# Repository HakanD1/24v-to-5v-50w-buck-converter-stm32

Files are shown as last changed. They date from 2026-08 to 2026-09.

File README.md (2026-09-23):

# STM32 Digitally Controlled 24V to 5V (50W) Buck Converter







A high-performance, fully custom **closed-loop digitally controlled buck converter** capable of stepping down a 24V DC input to a highly stable 5V DC output, providing up to 10A (50W) of continuous power. 

This project integrates custom PCB hardware, STM32 embedded software, mathematical control algorithms, and a Nextion HMI (Human-Machine Interface) into a single, cohesive industrial-grade prototype.
> ⚠️ **Project Status:** Rather than turning this into a physical product, I built it as an R&D exercise to combine the full design, simulation, and firmware development process into a single project and put my theoretical background into practice. As a result, the PCB, schematic, and firmware files in this repo have not been manufactured — they've only been verified through design and simulation.

## 🌟 Key Features

*   **Robust Power Delivery:** 24V to 5V step-down conversion with up to 10A current capacity.
*   **Digital PI Control:** Real-time Proportional-Integral (PI) control loop running on an STM32 microcontroller to dynamically adjust the 120 kHz PWM duty cycle for perfect voltage/current regulation.
*   **Precision Measurement:** Hall-effect current sensing (ACS712) and voltage divider networks, both buffered by MCP6001 Op-Amps for noise-immune ADC readings via DMA.
*   **Advanced Gate Driving:** FAN73711 high-speed gate driver implemented to efficiently switch the N-Channel power MOSFET with minimal switching losses.
*   **Multi-Stage Auxiliary Power:** Dual XL4015 buck stages (24V→12V, 12V→5V) and an AMS1117-3.3V LDO to safely isolate and power the logic and driver circuits.
*   **Comprehensive Protection:** Input fuse, varistor for overvoltage spikes, inrush current-limiting thermistor, and a software-controlled mechanical relay for emergency cutoff.
*   **Interactive UI:** Nextion display integration via USART for real-time monitoring (V, I, P) and on-the-fly PI tuning, calibration, and mode switching.

## 🛠️ Hardware Architecture

The custom dual-layer PCB is designed with best practices in mind, separating noisy power switching nodes from sensitive analog measuring circuits.

*   **Power Stage:** Features a 33µH power inductor and low-ESR capacitors optimized through MATLAB/Simulink and LTspice simulations to minimize output ripple.
*   **Protection Layer:** Hardware-level protection blocks ensuring safe start-up and transient spike absorption.
*   **Connectivity:** Features industry-standard ports including USB Type-C (for communication/future updates), 4-pin SWD (for flashing/debugging), and a 4-pin USART header for the HMI.

## 💻 Software & Control Strategy

Developed using **STM32CubeIDE** and the HAL library, the software architecture operates in a non-blocking, interrupt-driven manner:

1.  **ADC via DMA:** Voltage and current analog signals are continuously sampled in the background.
2.  **Calibration Layer:** Raw ADC data is scaled using dynamically adjustable calibration multipliers (`V_Cal`, `I_Cal`) and offsets to compensate for real-world component tolerances.
3.  **PI Algorithm:** Compares the measured value against the user-defined reference. The accumulated error (Integral) and current error (Proportional) dynamically update the timer's compare register to adjust the 120 kHz PWM duty cycle.
4.  **UART Parser:** A custom interrupt-driven parser processes commands from the Nextion screen (e.g., `KPV:2.50`, `SETV:5.00`) to tune the system on the fly.

## 📂 Repository Structure

*   `/bom` - Bill of Materials (BOM) files.
*   `/cubemx` - STM32CubeIDE project workspace and C/C++ source code.
*   `/gerber` - PCB manufacturing and Gerber files.
*   `/Nextion` - Nextion HMI display interface and GUI files.
*   `/schematic_pcb_3d` & `/STEP file` - 3D models and CAD files of the PCB.
*   `buck converter V6.*` - KiCad schematic and PCB design files.
*   `Buck_converter_24Vto5V.asc` - LTspice simulation model.
*   `buck_converter_24Vto5V.slx` - MATLAB/Simulink model.
*   `REPORT.pdf` - Comprehensive project documentation and theoretical calculations (in Turkish).

## 🚀 Getting Started

1.  Clone this repository: `git clone https://github.com/HakanD1/24v-to-5v-50w-buck-converter-stm32`
2.  Open the `/cubemx` project folder in **STM32CubeIDE**.
3.  Compile and flash the firmware onto the STM32F103C8T6 via the SWD interface.
4.  Load the `.tft` file (located in the `/Nextion` folder) onto your Nextion display.
5.  Supply 24V to the main input terminal, and monitor the live parameters on the Nextion screen.

## 📄 License

This project is licensed under the MIT License - see the [LICENSE](LICENSE) file for details.

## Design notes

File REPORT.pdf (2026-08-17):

# PROJE RAPORU

# STM32 Kontrollü 24 V–5 Buck Converter Tasarım

## Hazırlayan Hakan Dönmez

### Elektrik-Elektronik Mühendisliği

### Temmuz 2026

## 1. DEVRENİN ÇALIŞMA PRENSİBİ

Bu projenin temel amacı, giriş terminalinden uygulanan 24V DC gerilimi çıkışta

stabil bir 5V DC'ye düşüren ve 10A akım, 50W güç kapasitesi sunan bir buck converter

tasarlamaktır. Sistem, çıkış gerilimini ve akımını sürekli izleyerek closed-loop çalışan bir

güç kaynağı mimarisine sahiptir.

Sistemdeki farklı birimlerin çalışabilmesi için girişten alınan 24V besleme gerilimi

kademeli olarak düşürülmektedir. Bu doğrultuda, devrede iki adet XL4015 entegresi

kullanılarak sırasıyla 24V'tan 12V'a ve 12V'tan 5V'a düşürücü hatlar oluşturulmuştur. Ana

kontrol birimi olan STM32 mikrodenetleyicisi ve diğer dijital/analog komponentlerin

ihtiyaç duyduğu 3.3V besleme gerilimi ise, bu hattan beslenen bir AMS1117-3.3 LDO

aracılığıyla sağlanmaktadır. Ana güç dönüştürücünün aktarımı doğrudan STM32

mikrodenetleyicisi tarafından yönetilmektedir. Mikrodenetleyici, çıkış regülasyonunu

sağlamak için 120 kHz frekansında bir PWM sinyali üretir. Ancak STM32'nin 3.3V lojik

seviyesindeki çıkış sinyali, güç MOSFET'ini yüksek frekanslarda sürmek için tek başına

yeterli değildir. Bu sebeple devrede FAN73711 gate driver entegresi kullanılmıştır. Bu

driver, STM32'den gelen sinyali uygun seviyeye yükselterek MOSFET'in hızlı bir şekilde iletime ve kesime girmesini sağlar, böylece anahtarlama kayıpları en aza indirilir. İstenen

5V/10A çıkışın stabil kalması ve değişen yük durumlarında regülasyonun bozulmaması için

sistem bir geri besleme (feedback) mekanizması ile çalışır. Çıkış gerilimi ve hattan çekilen

akım değerleri, STM32'nin ADC pinleri üzerinden anlık olarak okunur. Okunan bu gerçek

değerler ile hedeflenen değerler arasındaki fark, mikrodenetleyici yazılımında koşan bir PI (Oransal-İntegral) kontrol algoritması tarafından işlenir. PI kontrolör, bu hatayı minimize

etmek üzere 120 kHz'lik PWM sinyalinin duty cycle değeri sürekli ve dinamik olarak

günceller.

Akım ölçümü için devrede ACS712 sensörü ve okunan sinyali mikrodenetleyiciye

uygun şekilde ölçeklendiren MCP6001 işlemsel op-amp yer almaktadır. Anahtarlama

gürültülerinin analog ölçümleri bozmaması amacıyla, STM32'nin analog besleme hattına

(VDDA) bir ferrite bead (FB1) eklenmiş ve yüksek kararlılıkta ADC okumaları elde

edilmesi hedeflenmiştir. Sistemin güvenliği ve dış donanım kontrolü için devreye bir adet

röle entegre edilmiştir. STM32 röle bobinini doğrudan süremediği için, kontrol işlemi bir

BC817 transistörünü tetikleyen GPIO pini üzerinden gerçekleştirilir. Sistemdeki anlık

gerilim, akım verileri ve genel çalışma durumu, STM32'nin USART1 hatları üzerinden

Nextion ekrana iletilerek kullanıcı arayüzüne aktarılır. Ayrıca, güç hatlarının durumunu

görselleştirmek için şemada durum LED'leri bulunmakta olup, cihazla iletişim ve yazılım

güncelleme işlemleri için bir USB Type-C portu ile BOOT0 butonu sisteme dahil edilmiştir.

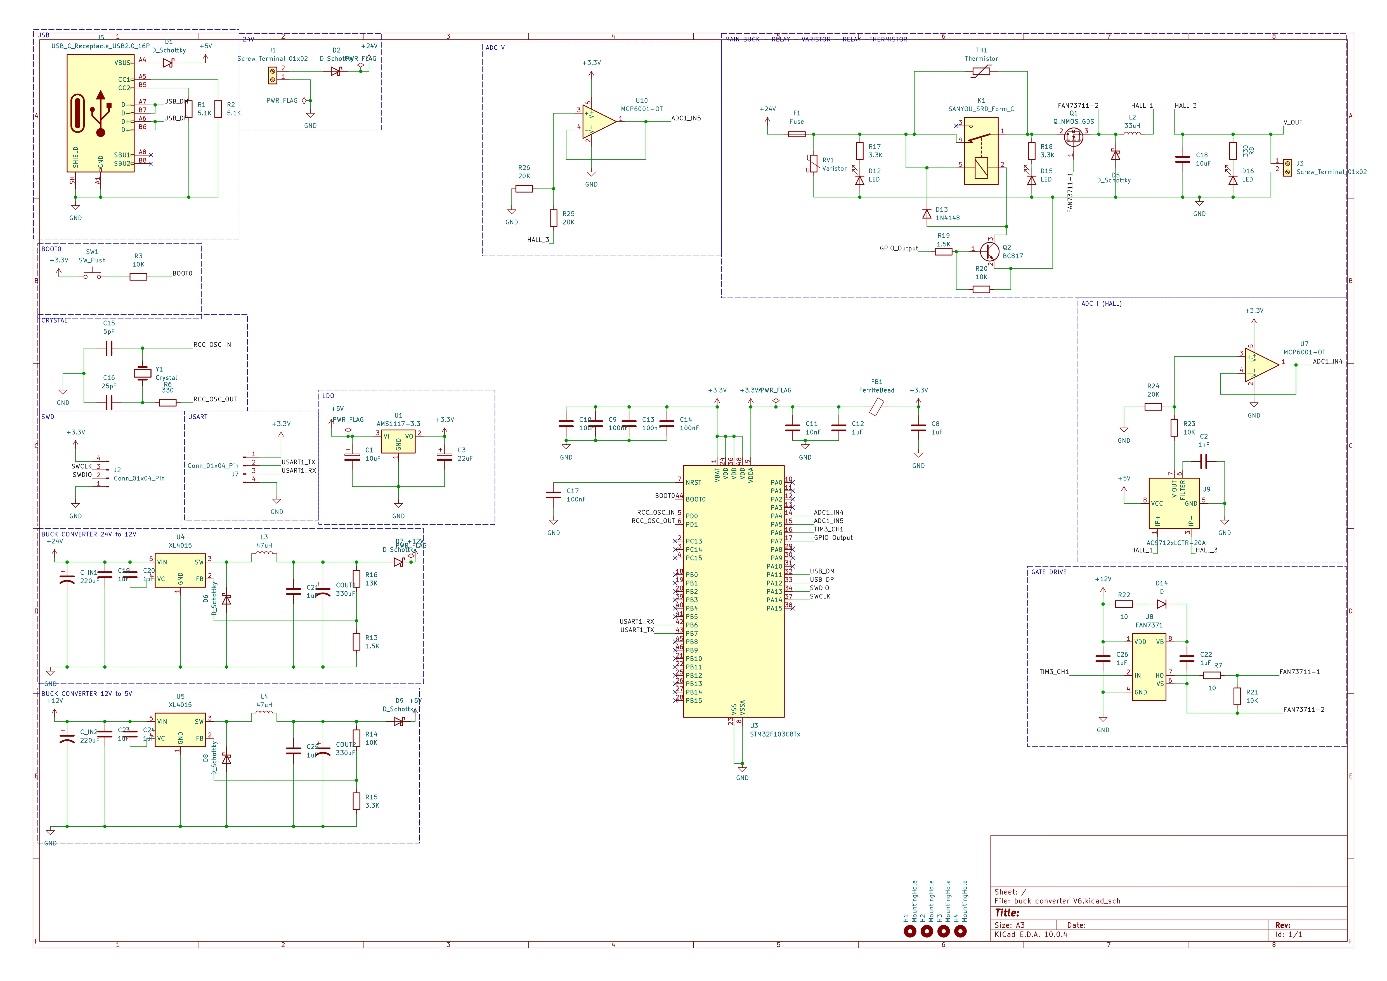
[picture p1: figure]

Şekil 1

## 2. SİSTEM MİMARİSİ VE YAPISI

### 1. BUCK CONVERTER 24V-12V, 12V-5V ve LDO Blokları

Sistemin ana güç aktarımından bağımsız olarak, STM32 ve Gate Driver birimlerinin

uyanıp çalışabilmesi için J1 terminalinden giren 24V ana besleme kademeli olarak

düşürülür. Bu amaçla, stok durumu, maliyet ve üretici datasheet yönergeleri göz önüne

alınarak iki adet XL4015 Buck seçilmiştir. Şemadaki U4 bloğu 24V girişini alıp Gate Driver

(FAN7371) için 12V üretirken; U5 bloğu bu 12V'u alarak sistemi besleyecek 5V gerilimini

elde eder. D2 diyodu ile ters akım koruma amacı ile yerleştirilmiştir.

Bu düşürücü bloklardaki pasif komponentler doğrudan datasheet referanslarıyla

belirlenmiştir. Temel enerji depolama ve büyük voltaj dalgalanmalarını sönümlemek için

girişte 220µF (CIN1, CIN2), çıkışta 330µF (COUT1, COUT2) alüminyum elektrolitik

kondansatörler kullanılmıştır. Anahtarlama sırasında oluşan yüksek frekanslı elektriksel

gürültüleri filtrelemek amacıyla da bu kondansatörlere paralel olarak daha hızlı tepki veren

düşük sığalı seramik kondansatörler (C19, C20 vb.) eklenmiştir. Akım dalgalanmasını

optimum seviyede tutmak için datasheet hesaplamalarına uygun 47µH bobinler (L3, L4) ve

anahtarlama esnasında akımın devreyi tamamlaması için D7/D9 Schottky diyotları devrede

yer alır. Çıkış gerilimlerini 12V ve 5V'a sabitlemek için ise geri besleme (FB) pinlerine

datasheet formüllerine göre belirlenmiş hassas direnç bölücüler (R13/R16 ve R14/R15)

bağlanmıştır.

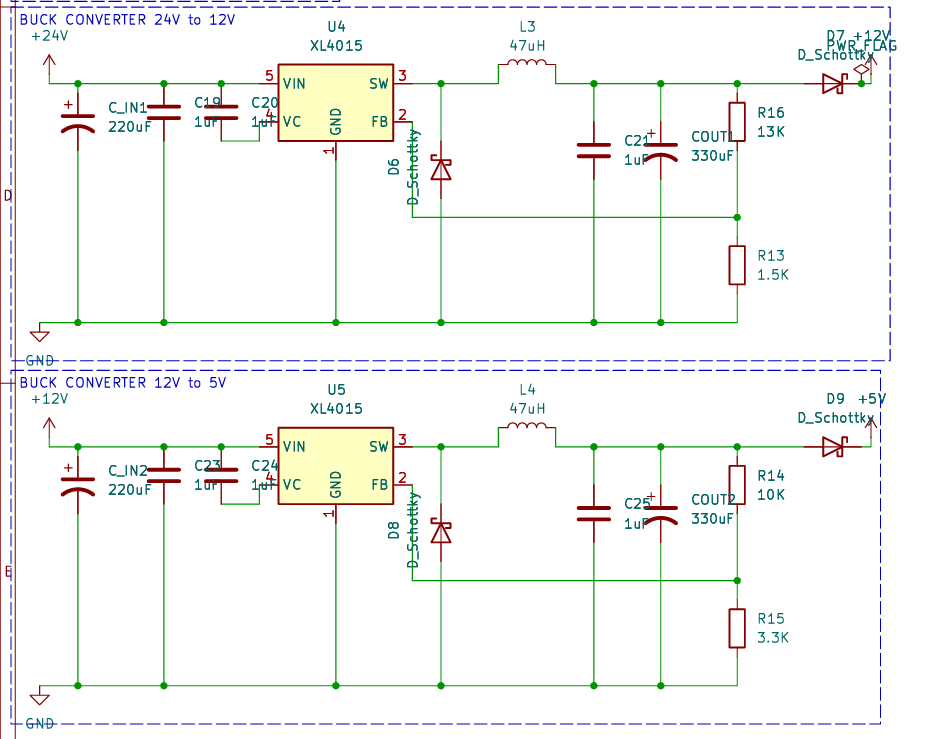
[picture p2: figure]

Şekil 2

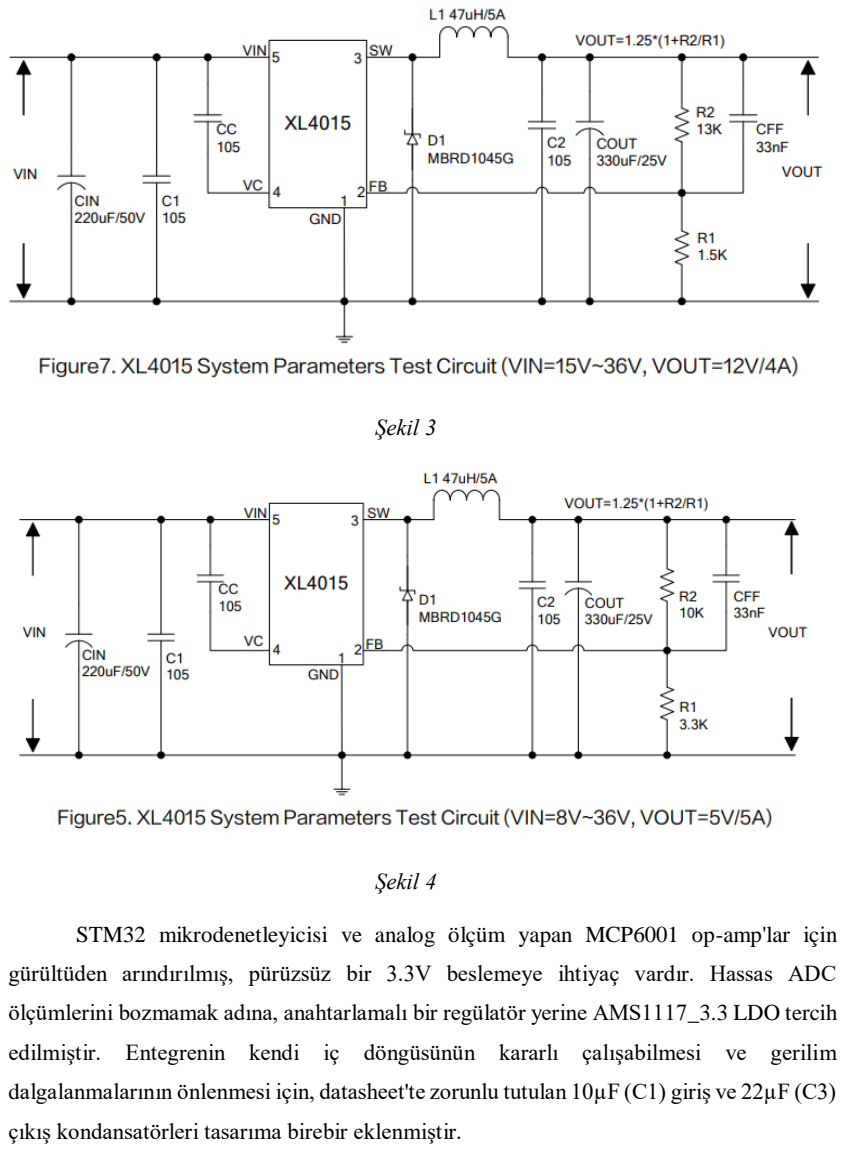
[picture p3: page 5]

Şekil 3

Şekil 4

STM32 mikrodenetleyicisi ve analog ölçüm yapan MCP6001 op-amp'lar için

gürültüden arındırılmış, pürüzsüz bir 3.3V beslemeye ihtiyaç vardır. Hassas ADC

ölçümlerini bozmamak adına, anahtarlamalı bir regülatör yerine AMS1117_3.3 LDO tercih

edilmiştir. Entegrenin kendi iç döngüsünün kararlı çalışabilmesi ve gerilim

dalgalanmalarının önlenmesi için, datasheet'te zorunlu tutulan 10µF (C1) giriş ve 22µF (C3)

çıkış kondansatörleri tasarıma birebir eklenmiştir.

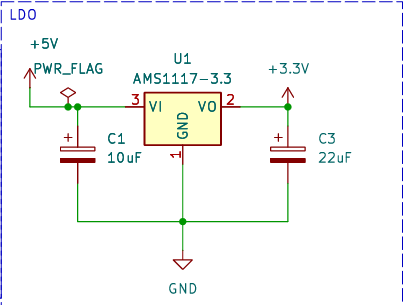
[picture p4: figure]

Şekil 5

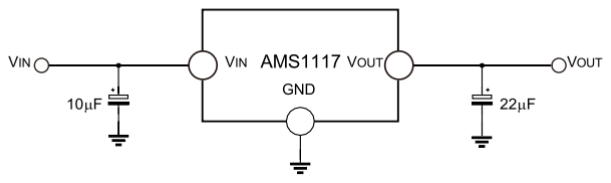
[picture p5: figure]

Şekil 6

### 2. STM32, CRYSTAL ve BOOT0 Blokları

Sistemin tüm kapalı çevrim kontrol algoritmalarını (PI kontrol), 120 kHz frekanslı

PWM üretimini ve kullanıcı arayüzü haberleşmesini yöneten ana beyin olarak

STM32F103C8T6 mikrodenetleyicisi kullanılmıştır. Mikrodenetleyicinin dijital besleme

(VDD) pinlerine, dijital işlemlerden kaynaklanan anlık gerilim düşümlerini ve gürültüleri

engellemek amacıyla 100nF değerinde decoupling kondansatörleri (C9, C10, C13, C14)

yerleştirilmiştir. Ayrıca, akım ve gerilim ölçümlerinin yapıldığı hassas analog besleme hattı

(VDDA), anahtarlama gürültülerinden etkilenmemesi için dijital hattan bir ferrite bead

(FB1) ile izole edilmiş ve ADC okumalarının kararlılığı güvence altına alınmıştır.

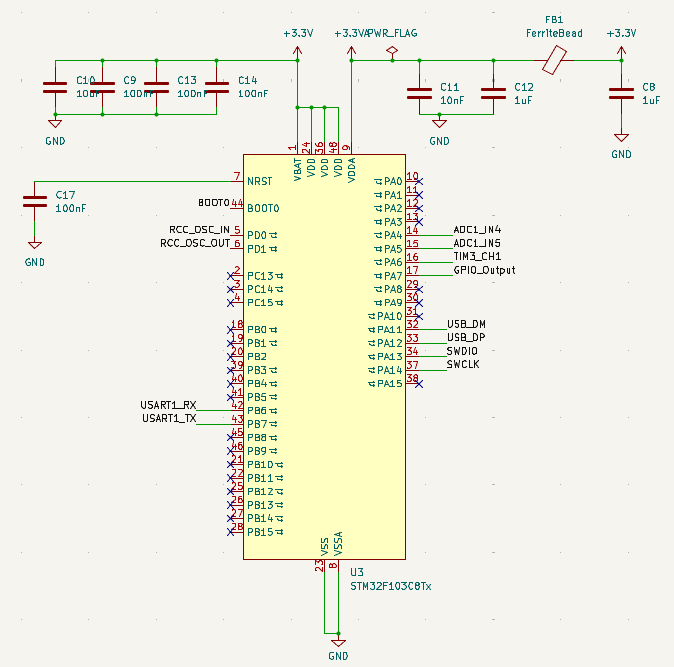
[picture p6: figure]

Şekil 7

Sistemde yüksek frekanslı PWM sinyallerinin hassas bir şekilde üretilebilmesi ve

UART gibi zamanlamaya duyarlı haberleşme protokollerinin sorunsuz çalışabilmesi için

mikrodenetleyicinin dahili osilatörü yerine harici bir kristal osilatör devresi tercih

edilmiştir. Kullanılan kristalin kararlı bir şekilde titreşime geçebilmesi ve dış etkenlere bağlı

frekans kaymalarının önlenmesi için, datasheet yönergelerine uygun olarak 25pF değerinde

yük kondansatörleri (C15, C16) ile desteklenmiştir.

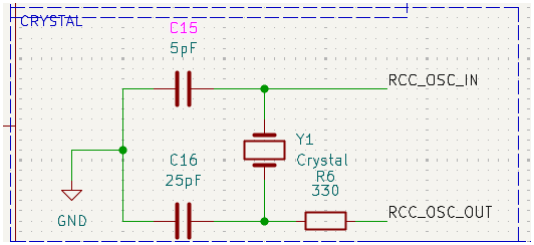
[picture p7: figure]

Şekil 8

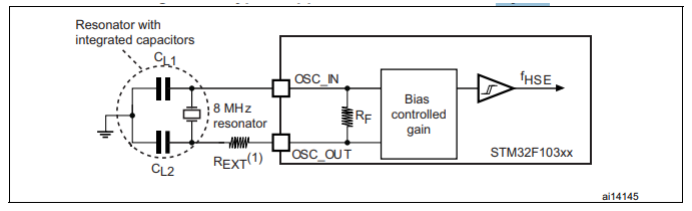
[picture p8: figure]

Şekil 9

Cihazın programlanması ve yazılım güncellemelerinin kolayca yapılabilmesi için

donanımsal bir BOOT0 kontrol bloğu tasarıma dahil edilmiştir. BOOT0 pini, normal

çalışma durumunda 10k değerinde bir direnç (R3) ile toprağa çekilerek (pull-down)

sistemin her açılışta ana hafızadan başlaması güvence altına alınmıştır. Yazılım atılacağı

zaman ise bir push buton (SW1) vasıtasıyla bu pine 3.3V verilerek mikrodenetleyicinin

donanımsal olarak bootloader moduna geçmesi sağlanır. Ek olarak, elektriksel gürültülerin

veya dalgalanmaların mikrodenetleyiciyi yanlışlıkla resetlemesini engellemek amacıyla

NRST pinine 100nF değerinde bir filtre kondansatörü (C17) eklenmiştir.

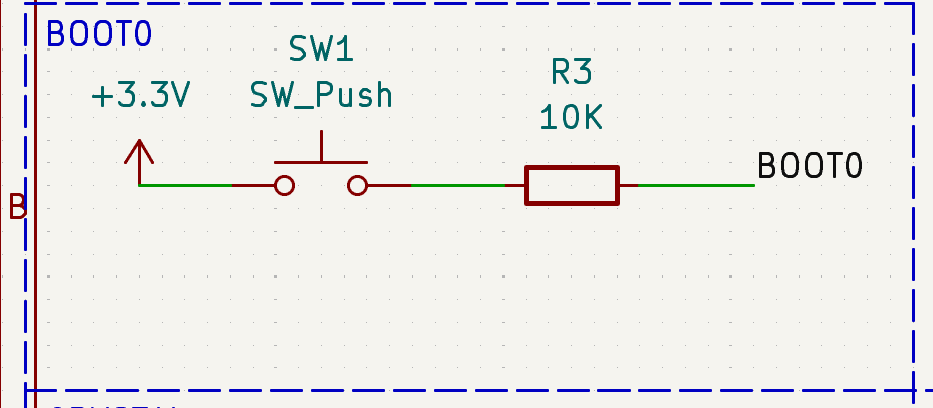
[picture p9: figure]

Şekil 10

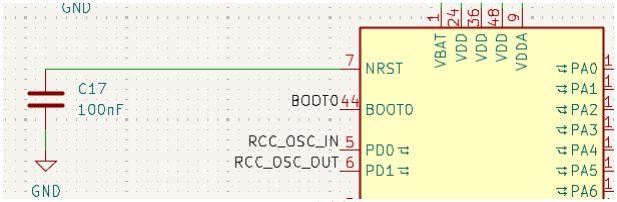
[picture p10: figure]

Şekil 11

### 3. MAIN BUCK ve GATE DRIVE Blokları

Devrenin temel amacı olan 24V girişten 5V ve 10A (50W) regüleli çıkış elde etme

işlemi bu katmanda gerçekleşir ve sistemin verimliliği açısından en kritik bölümdür.

STM32 tarafından üretilen 3.3V lojik seviyesindeki 120 kHz frekanslı PWM sinyali, güç

MOSFET'inin (Q1) gate kapasitansını bu kadar yüksek hızlarda kayıpsız sürmek için tek

başına yeterli değildir. Bu nedenle aracı bir driver olarak 12V ile beslenen FAN7371

entegresi kullanılmıştır. Sistemde N-Kanal bir MOSFET konumlandırıldığı için, driver

devresinde D14 diyotu ve C22 (1µF) kondansatörü ile bir bootstrap devresi oluşturularak

MOSFET'in tam iletime geçmesi için gereken yüksek geçit gerilimi sağlanmıştır.

MOSFET'in iletime geçme hızını kontrol etmek ve elektromanyetik gürültüleri önlemek

için geçit ucuna 10 ohm değerinde bir seri direnç (R7) eklenmiş; driver pasifken

MOSFET'in güvenli bir şekilde kesimde kalmasını garanti altına almak için ise 10k

değerinde bir pull-down direnci (R21) kullanılmıştır.

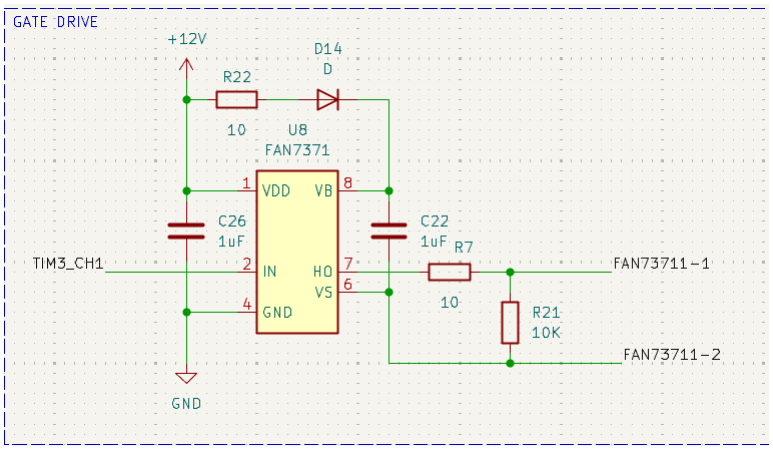
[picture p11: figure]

Şekil 12

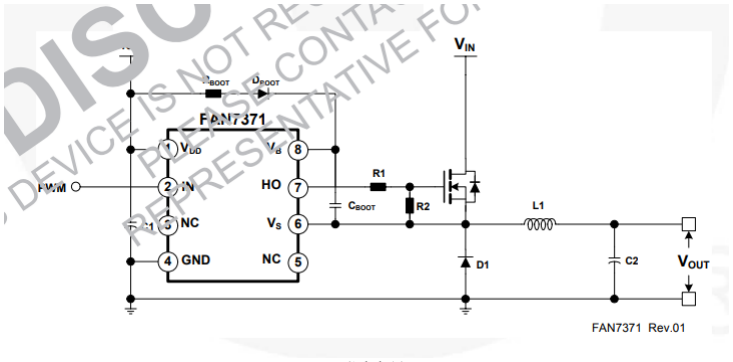
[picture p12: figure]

Şekil 13

Dönüştürücü topolojisinin anahtarlama elemanı olarak, ısıl kayıpları minimumda

tutmak adına düşük iletim direncine sahip bir N-Kanal MOSFET (Q1) görev yapmaktadır.

MOSFET kesime gittiğinde bobin üzerinde biriken manyetik enerjinin devreyi

tamamlaması işlemi, anahtarlama hızlarına ayak uydurabilen ve ileri yön gerilim düşümü

düşük olan bir Schottky diyot üzerinden sağlanmaktadır. Güç aktarımının ana pasif

elemanları olan 33µH değerindeki L2 bobini ve 10µF değerindeki C18 çıkış kondansatörü,

Bölüm 3’te detaylandırılan MATLAB/Simulink ve LTspice simülasyon testleri sonucunda elde edilen optimum kararlılık verilerine dayanılarak belirlenmiştir. 120 kHz gibi yüksek

bir anahtarlama frekansı kullanılması sayesinde hem bobinin fiziksel boyutu küçültülmüş

hem de 10A gibi yüksek bir akımda bile çıkış dalgalanması simülasyonlarda hedeflenen

ideal seviyelerde tutulmuştur.

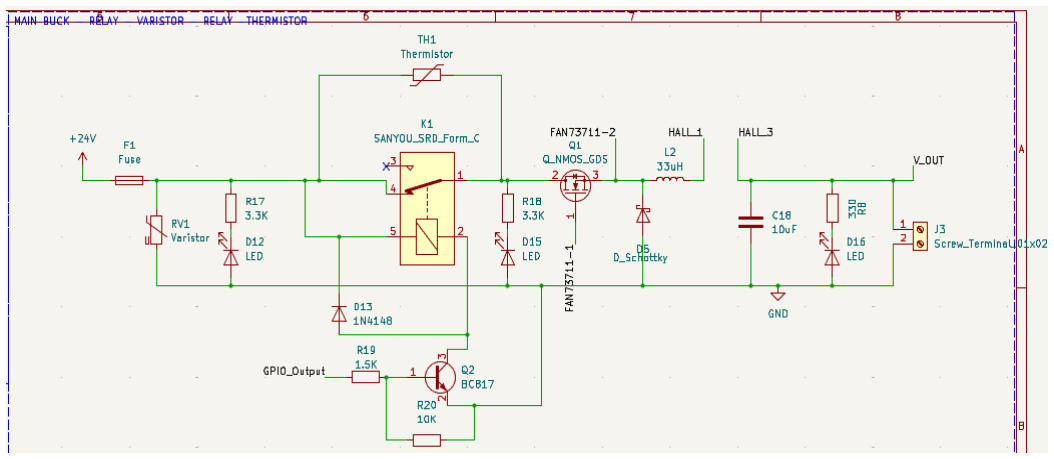
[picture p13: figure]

Şekil 14

Sistemdeki güç akışını ve donanımın çalışma durumunu görsel olarak anlık takip

edebilmek amacıyla devrenin kritik noktalarına durum LED'leri (D12, D15 ve D16)

yerleştirilmiştir. Bu LED'ler, röle sonrası güç hattının, anahtarlama katının ve regüle edilmiş

5V ana çıkışın (V_OUT) aktif olup olmadığını kullanıcıya donanımsal bir geri bildirim

olarak sunar. Bu kattaki güç bileşenlerinin tamamı, çıkışta hedeflenen sürekli 10A akım

yükünü ısıl ve elektriksel olarak güvenle taşıyabilecek toleranslara sahip parçalar arasından

seçilmiştir. Seçim sürecinde donanımların piyasadaki stok durumu, uygun maliyetli

olmaları ve güvenli çalışma sınırlarına tam uyumları en temel kriterler olmuştu

### 4. ADC_V ve ADC_I Blokları

Sistemin kapalı çevrim kontrol yapabilmesi ve aşırı akım koruması sağlayabilmesi

için çıkış geriliminin ve akımının anlık olarak ölçülmesi gerekmektedir. Çıkış geriliminin

(V_OUT) okunması işlemi ADC_V bloğunda gerçekleştirilir. STM32'nin analog giriş

pinleri maksimum 3.3V referans değerine kadar okuma yapabildiği için, 5V'luk ana çıkış

gerilimi doğrudan mikrodenetleyiciye verilmez; bunun yerine R25 (20k) ve R26 (20k)

dirençlerinden oluşan bir gerilim bölücü ağ ile yarı yarıya (1/2 oranında) düşürülür. ADC

pinine giden sinyalin empedansını düşürmek ve dış gürültülerden arındırılmış kararlı bir okuma sağlamak amacıyla, bu zayıflatılmış sinyal U10 referanslı MCP6001 işlemsel

yükselteci (op-amp) üzerinden geçirilir. Bir gerilim izleyici (voltage follower/buffer) olarak

kurulan bu op-amp'ın çıkışı, ölçüm yapılabilmesi için mikrodenetleyicinin ADC1_IN5

pinine iletilir.

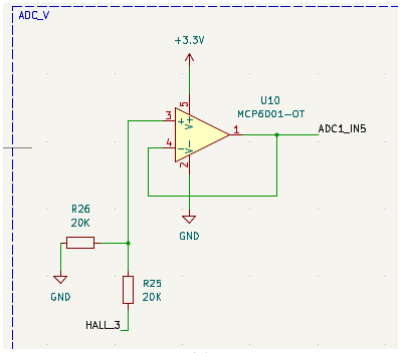
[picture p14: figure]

Şekil 15

Çıkış akımının ölçümü için ADC_I bloğunda Hall-effect (manyetik) prensibiyle

çalışan ACS712xLCTR-20A akım sensörü kullanılmıştır. Bu sensör, akım yoluna fiziksel

bir şönt direnç eklemediği için devrede güç kaybı (insertion loss) yaratmaz ve ölçüm katını

yüksek akım hattından elektriksel olarak tamamen izole eder. ACS712 sensörü 5V besleme

ile çalıştığı için, okuduğu akım değerine göre ürettiği analog çıkış voltajı

mikrodenetleyicinin 3.3V'luk güvenli okuma sınırını aşabilmektedir. Bu donanımsal sorunu

çözmek için sensör çıkışına R24 (20k) ve R23 (10k) dirençlerinden oluşan bir bölücü ağ

eklenerek sinyal genliği güvenli bir seviyeye ölçeklenmiştir. Sinyal üzerindeki elektriksel

gürültüleri filtrelemek ve sensörün bant genişliğini ayarlamak için sensörün FILTER pinine

1nF değerinde bir kondansatör (C2) bağlanmıştır. Voltaj okuma bloğunda olduğu gibi, akım

sensöründen gelen bu ölçeklenmiş sinyal de U7 referanslı bir diğer MCP6001 op-amp ile

tamponlanarak (buffer) mikrodenetleyicinin ADC1_IN4 pinine güvenli bir şekilde aktarılır.

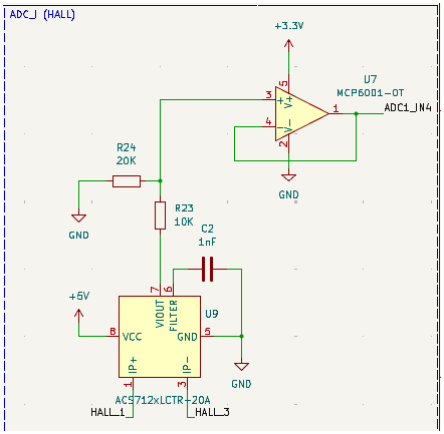
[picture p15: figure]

Şekil 26

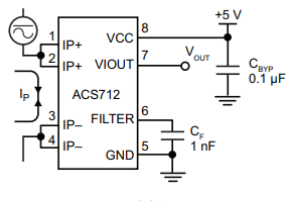
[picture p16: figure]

Şekil 17

### 5. PIN ÇIKIŞLARI ve ARAYÜZ (USART, SWD, USB)

Sistemin dış dünya ile haberleşmesi, programlanması ve harici donanım bağlantıları

için çeşitli arayüz portları şemaya entegre edilmiştir. Güncel bağlantı standartlarına uygun

olarak tasarıma 16 pinli bir USB Type-C portu (J1) eklenmiştir. Bu port üzerinden

mikrodenetleyicinin PA11 ve PA12 pinlerine USB veri hatları (USB_DM ve USB_DP)

yönlendirilmiştir. Cihazın bağlandığı güç kaynağına kendini standart bir enerji tüketicisi

(UFP) olarak tanıtabilmesi için, Type-C bağlantı spesifikasyonlarına tamamen uygun

şekilde CC1 ve CC2 konfigürasyon pinlerine 5.1k değerinde pull-down dirençleri (R1 ve

R2) eklenmiştir.

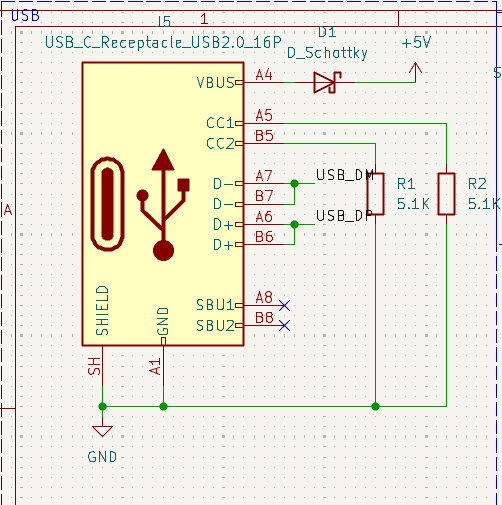
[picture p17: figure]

Şekil 18

Mikrodenetleyicinin programlanması ve donanımsal hata ayıklama işlemlerinin kart

üzerinde pratik şekilde gerçekleştirilebilmesi için 4 pinli standart bir SWD konnektörü (J2)

tasarlanmıştır. | Bu | konnektör | üzerinden | +3.3V | besleme, | GND | hatları | ve

mikrodenetleyicinin PA13 (SWDIO) ile PA14 (SWCLK) pinleri doğrudan dışarıya

aktarılmıştır. Sistemin harici donanımlarla ve özellikle kullanıcı arayüzü ile (HMI/Ekran)

seri haberleşebilmesi amacıyla donanıma 4 pinli bir USART konnektörü (J7) de dahil

edilmiştir. Bu port üzerinden cihazın toprağı (GND), +3.3V beslemesi ve

mikrodenetleyicinin PB6 (USART1_TX) ile PB7 (USART1_RX) pinleri dış bağlantıya

sunularak çift yönlü seri veri alışverişi fiziksel olarak mümkün kılınmıştır.

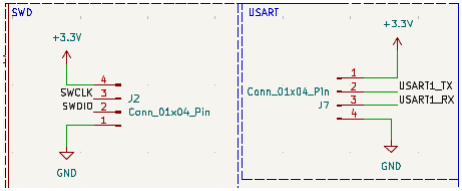
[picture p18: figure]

Şekil 19

### 6. KORUMA ve GÖSTERGE Blokları (Relay, Varistor, Thermistor, Fuse)

Sistemin ana enerji girişinde, donanımı ve yükü olası elektriksel tehlikelere karşı

güvence altına almak amacıyla kapsamlı bir koruma katı tasarlanmıştır. Dışarıdan uygulanan

24V besleme hattında, kısa devre ve tolerans dışı aşırı akım durumlarında devreyi fiziksel

olarak kesmek için Fuse hatta seri olarak eklenmiştir. Şebeke veya güç kaynağından gelebilecek

anlık aşırı gerilim sıçramalarına karşı devreyi korumak ve bu gerilimi kendi üzerinde

sönümlemek amacıyla hatta paralel olarak RV1 varistörü yerleştirilmiştir. Ayrıca, sisteme ilk

enerji verildiğinde devredeki yüksek kapasiteli boş kondansatörlerin aniden dolmaya

çalışmasıyla oluşabilecek tehlikeli demeraj akımını (inrush current) güvenli bir seviyede

sınırlamak için hatta seri olarak TH1 termistörü konumlandırılmıştır.

Main Buck bloğuna giden güç akışını yazılımsal olarak kontrol edebilmek ve aşırı akım

gibi acil durumlarda gücü fiziksel olarak tamamen kesebilmek için SANYOU SRD serisi bir

elektromekanik röle | kullanılmıştır. | Mikrodenetleyiciden gelen 3.3V seviyesindeki

GPIO_Output röle bobinini doğrudan süremeyeceği için, röle Q2 (BC817) NPN transistörü

kullanılarak anahtarlanmaktadır. Transistörün iletime geçme akımını ayarlamak için baz ucuna

R19 (1.5k) direnci, röle pasifken transistörün kararlı bir şekilde kesimde kalmasını sağlamak

için ise R20 (10k) pull-down direnci eklenmiştir. Röle bobininin enerjisi kesildiğinde oluşacak

yüksek gerilimli ters elektromotor kuvvetinden sürücü transistörü korumak amacıyla, bobine

ters paralel olarak D13 (1N4148) flyback diyotu bağlanmıştır.

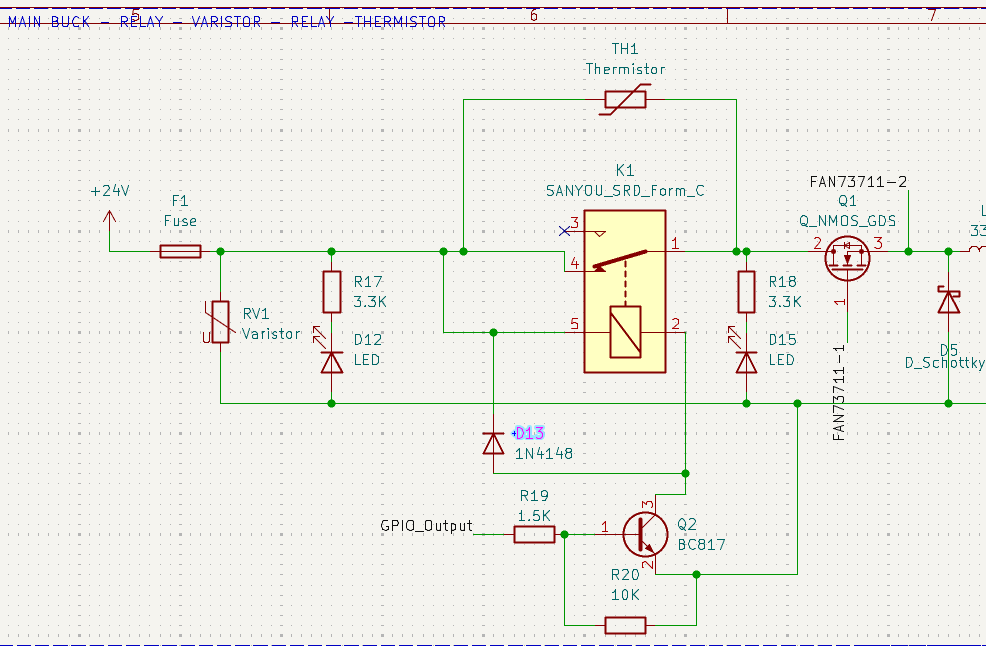
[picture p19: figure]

Şekil 20

## 3. SİMÜLASYON VE TASARIM DOĞRULAMA

Sistemin ana düşürücü (main buck) katı oluşturulmadan önce, teorik hesaplamaları

doğrulamak ve deneme yanılma yoluyla optimum komponent değerlerini (L ve C) bulmak

amacıyla MATLAB/Simulink ve LTspice programları kullanılarak kapsamlı simülasyon testleri

gerçekleştirilmiştir. Bu aşamada sistem hem kapalı çevrim kontrol tepkisi hem de açık çevrim

elektriksel güç analizi yönünden incelenmiştir.

Sistemin dinamik yük değişimlerine karşı vereceği tepkiyi ve PI kontrolcünün

kararlılığını test etmek için Simulink üzerinde bir closed-loop buck konvertör modeli

kurulmuştur. Modelde, 5V'luk referans gerilim değeri ile sistemin anlık çıkış gerilimi

karşılaştırılarak elde edilen hata sinyali bir PID kontrol blokuna beslenmiştir. Kontrolcüden

çıkan sinyal, bir sawtooth dalga üreteci ile ilişkisel operatör üzerinden karşılaştırılarak,

donanımdaki STM32'nin ürettiği PWM sinyali simüle edilmiştir. Simülasyon sonucunda,

sistemin 5V hedefine çok yüksek bir hassasiyetle ulaştığı (ekranda okunan 4.981 V) ve test

yükü üzerinde yaklaşık 4.86 A akım akıttığı doğrulanarak kontrol algoritmasının başarıyla

çalıştığı kanıtlanmıştır.

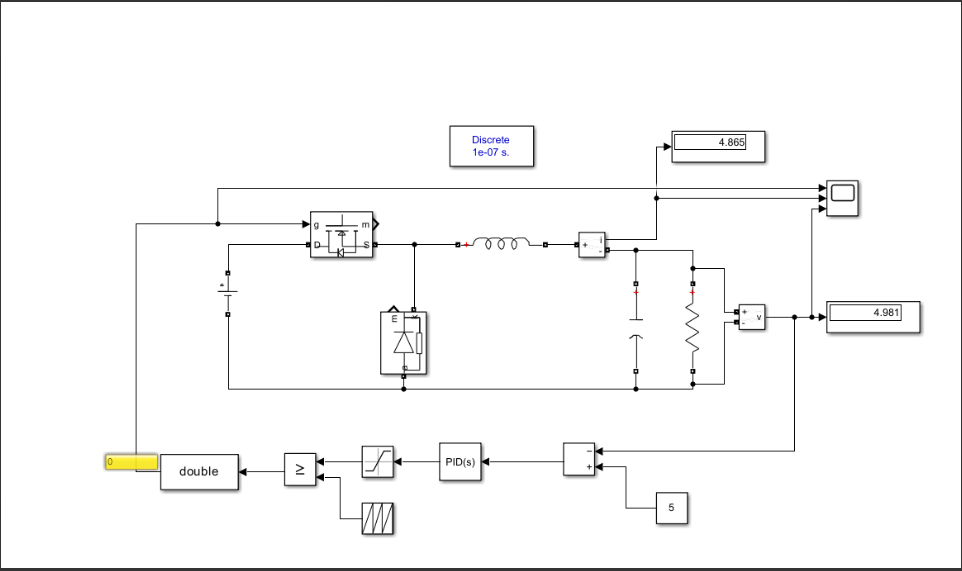
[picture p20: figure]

Şekil 21

Yüksek frekanslı anahtarlama sırasında güç elemanlarının elektriksel karakteristiklerini

ve sistemin transient tepkisini incelemek amacıyla gerçeğe en yakın parametrelerle bir LTspice

devresi kurulmuştur. Simülasyon, 24V giriş, 33µH anahtarlama bobini ve 10µF çıkış

kondansatörü ile oluşturulmuştur. Tasarımın tam kapasitedeki (50W) sınırlarını ve kararlılığını

test etmek için çıkışa 0.5 ohm değerinde bir yük direnci eklenmiş, böylece devreden hedeflenen

maksimum akım olan 10A'in çekilmesi sağlanmıştır. Gate driver sinyali, donanımdaki 120

kHz'lik çalışma frekansını temsil edecek şekilde 8.33µs periyotlu ve 12V genlikli bir darbe

kaynağı olarak modellenirken; iletim kayıplarının doğru yansıtılması için ideal bileşenler yerine

IRF7468 N-Kanal MOSFET ve B540C Schottky diyot modelleri kullanılmıştır. Elde edilen 10

milisaniyelik simülasyon çıktısı incelendiğinde, ilk enerji verildiğinde çıkış geriliminin ve yük

akımının herhangi bir tehlikeli aşırı sıçrama yapmadan yaklaşık 0.5 milisaniye gibi çok kısa bir

sürede hedeflenen 5V ve 10A steady-state değerlerine yumuşak bir şekilde ulaştığı

gözlemlenmiştir. Grafikte akım ve gerilim eğrilerinin tam bir stabilite içinde, öngörülen çok

düşük bir dalgalanma bandı içerisinde seyretmesi; main buck katı oluşturulmadan önce deneme

yanılma testleriyle bulunan 33µH bobin ve 10µF kondansatör seçiminin en ağır yük altında bile

ne kadar optimum çalıştığını kanıtlamaktadır.

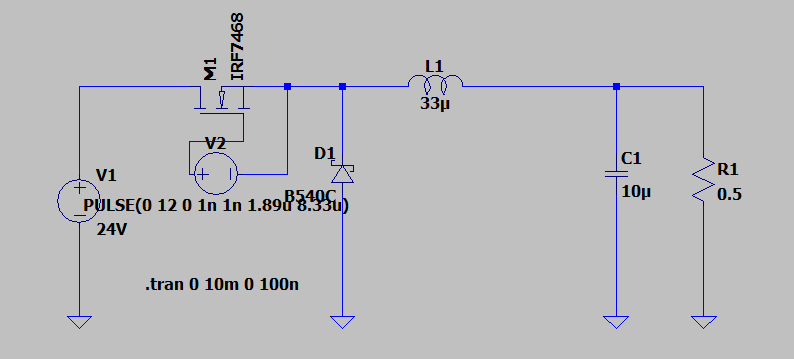
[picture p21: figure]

Şekil 21

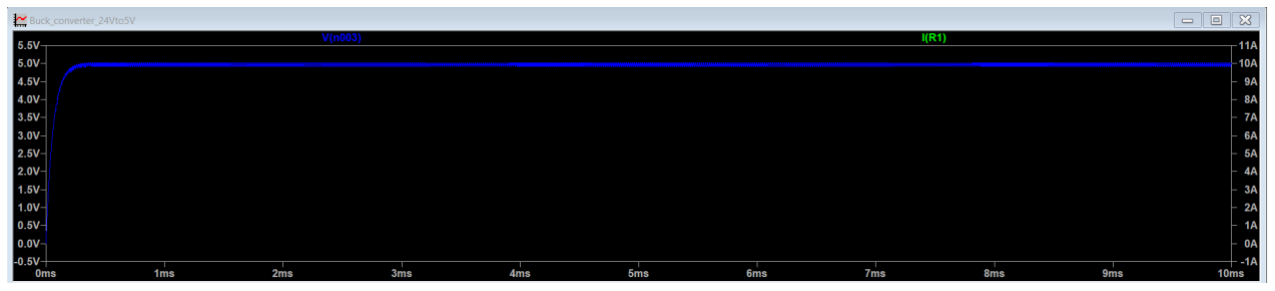
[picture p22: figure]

Şekil 22

### 4. KOMPONENT SEÇİM KRİTERLERİ

Tasarımda yer alan tüm donanım bloklarındaki elemanlar; sistemin 50W tam yük altında

kararlı, güvenli ve elektriksel gürültülerden uzak çalışabilmesi için termal dayanım, güvenli

çalışma alanı limitleri ve parazitik etkiler göz önüne alınarak seçilmiştir. Ana güç katında,

yüksek frekanslı anahtarlama kayıplarını ve ısınmayı minimize etmek için düşük iletim dirençli

(Rds(on)) MOSFET'ler ve hızlı toparlanma süresine sahip Schottky diyotlar kullanılmıştır. Ana

bobin, tepe akımlarında doymaması için yüksek doyum ve düşük iç direnç değerlerine; filtre

kondansatörleri ise dalgalanmaları ısınmadan sönümleyebilmesi için düşük eşdeğer seri direnç

yapısına sahip modellerden tercih edilmiştir.

Sistemin güvenliğini sağlayan koruma katmanında; giriş anormalliklerine, aşırı gerilim

sıçramalarına ve inrush akımına karşı donanımı savunmak üzere sırasıyla sigorta, varistör ve

termistör entegre edilmiştir. Ayrıca acil durumlarda ana gücü fiziksel olarak kesmek için

elektromekanik röle ve sürücüleri zıt EMK etkilerinden korumak için flyback diyotları eklenmiştir. Ölçüm hassasiyetini artırmak ve sinyal bütünlüğünü korumak adına, güç hattında

voltaj düşümü yaratmayan izolasyonlu Hall-effect akım sensörü (ACS712) ile sensörlerden

gelen sinyalleri gürültüsüz şekilde mikrodenetleyiciye aktaran düşük ofsetli op-amp'lar

(MCP6001) kullanılmıştır.

Kontrolcü ve sürücü entegrelerin kararlı uyanması için yardımcı besleme katında

yüksek verimli düşürücü regülatörler (XL4015) ve düşük gürültülü LDO konumlandırılmıştır.

Yüksek frekanslı parazitleri önlemek amacıyla tüm entegrelerin besleme bacaklarına dekuplaj

kondansatörleri yerleştirilirken; kullanıcı etkileşimi ve haberleşme için endüstri standardı

portlar (USB Type-C, SWD, USART) ile sistemin elektriksel durumunu anlık gösteren düşük

akım sarfiyatlı durum LED'leri de tasarıma dahil edilerek komponent seçimi tamamlanmıştır.

## 5. YAZILIM VE KULLANICI ARAYÜZÜ (HMI)

### 5.1. STM32 Gömülü Yazılım Mimarisi

Yazılım STM32CubeIDE'de HAL kütüphaneleriyle yazılmıştır. Sistem saati harici

kristalden (HSE) PLL ile çarpılarak 48 MHz'e çıkarılır ve bu saat üzerinden TIM3 zamanlayıcısı

120 kHz'lik PWM sinyalini üretir, bu sinyal MOSFET'i sürüp buck dönüştürücünün

anahtarlamasını sağlar. Gerilim ve akım ölçümleri ADC üzerinden DMA ile arka planda alınır,

işlemci beklemeden son değeri kullanır. Ham ADC değeri (0-4095) önce gerçek voltaja (0-

3.3V) çevrilir, ardından devredeki gerilim bölücü ve akım sensörünün kendi katsayılarıyla

gerçek çıkış gerilimi ve akımına dönüştürülür.

Bu ölçümlerin üzerine bir kalibrasyon katmanı eklenmiştir, çünkü sensör ve dirençlerin

üretim toleransı yüzünden ölçülen değer gerçek değerden sapabilir. Her ölçüme bir çarpan

(V_Cal, I_Cal) ve bir sabit ekleme (V_Offset, I_Offset) uygulanır:

out_voltage = (raw_voltage * V_Cal) + V_Offset,

out_current = (raw_current * I_Cal) + I_Offset

Çarpan, ölçümün eğimindeki hatayı düzeltir; örneğin çıkış gerçekte 5.00V iken kart

4.90V okuyorsa V_Cal ile bu oran düzeltilir. Ofset ise sabit bir kaymayı düzeltir; örneğin akım

sıfırken sensör 0A yerine 0.10A gösteriyorsa I_Offset ile bu fark çıkarılır. Bu dört değer

ekrandan CALV, OFFV, CALI, OFFI komutlarıyla değiştirilebilir; yani kart üretildikten sonra referans bir multimetre/ampermetre ile karşılaştırılıp sahada kalibre edilir, koda dokunmaya

gerek kalmaz.

Kontrol tarafında PI algoritması röle açıkken (Relay_State=1) ve gerilim ya da akım modu seçiliyken çalışır. Önce hata bulunur: hedef değer eksi ölçülen değer (gerilim modunda

V_Ref - out_voltage, akım modunda I_Ref - out_current). Bu hata her döngüde Ki katsayısıyla

çarpılıp integral terimine eklenir (integral_V += Ki_V * hata); yani geçmişte biriken tüm hata

toplanır, kalıcı hatayı sıfırlayan kısım budur. Aynı anki hataya da Kp çarpılıp orantılı terim

bulunur, ikisi toplanarak duty cycle hesaplanır (duty = Kp*hata + integral). Hem integral hem

son duty değeri 0-399 aralığında sınırlanır; bu sınırlama olmasaydı sistem hedefe uzun süre

ulaşamadığında integral aşırı büyür, hedefe ulaşıldığında bile freni tutamayıp aşım yapardı.

Hesaplanan duty değeri doğrudan zamanlayıcının karşılaştırma register'ına yazılır ve

MOSFET'in açık kalma süresini, dolayısıyla çıkış gerilimini/akımını belirler. Röle

kapatıldığında hem PWM hem integral sıfırlanır, sistem tekrar açıldığında birikmiş hata

olmadan başlar. Aşırı akım koruması her döngüde kontrol edilir, akım 12A sınırını geçerse röle

kapatılır ve duty sıfırlanır.

Ekranla haberleşme UART kesmesiyle yürütülür; gelen karakterler kesme içinde tek tek

okunup satır sonuna kadar tamponlanır, komutun asıl çözümü kesme dışında ana döngüde

yapılır. Komutlar "KOMUT:değer" formatında gelir, ilgili değişkene yazılır (mod, röle,

referans, PI katsayıları, kalibrasyon, manuel duty). Ekrana bilgi gönderimi 200ms'de bir,

HAL_GetTick() ile zaman takibi yapılarak, anlık gerilim/akım/güç değerlerinin metne çevrilip

UART'tan yollanmasıyla olur.

### 5.2. Ekran Arayüzü (Nextion) Tasarımı

Ekranda üç ölçüm kutusu (I, V, P), mod seçim butonu (Manuel / PI_I / PI_V), Relay

butonu, OFF/ON durum göstergesi, Ref, Offset, Cal, Kp, Ki giriş kutuları ve bunları karta

göndermek için bir Apply butonu bulunur. Kullanıcı bu kutulara istediği değerleri (referans, PI

katsayıları, ofset, kalibrasyon) girip Apply'a bastığında, Nextion bu bilgileri "KPV:2.50" gibi

metin komutları haline getirip UART üzerinden STM32'ye gönderir. Mod ve Relay butonları

da aynı şekilde her basışta "MODE:1" veya "RELAY:1" gibi komutlar üretir; böylece kullanıcı

sistemi Manuel, Sabit Voltaj (PI_V) veya Sabit Akım (PI_I) modunda çalıştırabilir, röleyi açıp

kapatabilir. STM32 tarafında bu komutlar kesme ile karakter karakter okunur, satır sonu geldiğinde tamamlanmış kabul edilir, komut ismine bakılarak (SETV, KPV, MODE, RELAY

vb.) hangi değişkenin güncelleneceği belirlenir ve ":" sonrasındaki sayı o değişkene yazılır.

Kart tarafında ise gerilim ve akım, ADC ile ölçülür; iki kanal DMA yöntemiyle sürekli

okunarak işlemci meşgul edilmeden veri alınır. Ham ADC değerleri önce gerilime, sonra devre

oranları ve akım sensörüne (ACS712) göre gerçek voltaj/akım değerine çevrilir, kullanıcının

girdiği kalibrasyon ve ofset katsayılarıyla düzeltilir; güç değeri de bu ikisinden hesaplanır. Bu

üç değer (akım, voltaj, güç) her 200 ms'de bir "t0.txt=değer" formatında ve Nextion'ın beklediği

bitiş baytlarıyla (0xFF 0xFF 0xFF) ekrana geri gönderilir, böylece I, V, P kutuları anlık olarak

güncellenir. Ayrıca akım 12A sınırını aşarsa yazılım röleyi otomatik keser ve bu durum OFF

göstergesine yansır. Böylece ekran hem kullanıcının sisteme komut verdiği hem de kartın anlık

ölçüm sonuçlarını kullanıcıya gösterdiği çift yönlü bir arayüz olarak çalışır.

## 6. PCB TASARIMI VE 3B MODELLEME

Kart, çift katmanlı olarak tasarlanmıştır. Üst katman büyük ölçüde sinyal ve güç

hatlarının yönlendirilmesi için kullanılırken, alt katman mümkün olduğunca kesintisiz

bırakılarak tüm devre için ortak bir GND düzlemi oluşturulmuştur. Bu yaklaşımın amacı, dönüş

akımlarının en kısa ve en düşük empedanslı yoldan geçmesini sağlamak, döngü alanlarını

küçültmek ve böylece anahtarlamadan kaynaklanan elektromanyetik gürültünün (EMI)

yayılımını azaltmaktır. Alt katmandaki bu düzlemin bölünmemesine özellikle dikkat edilmiş,

zorunlu geçişler dışında GND bütünlüğü kesintiye uğratılmamıştır.

Hat kalınlıkları, 1 oz bakır kalınlığı referans alınarak üzerlerinden geçecek akım

değerlerine göre hesaplanmıştır. Kontrol ve sinyal hatları (UART, ADC giriş hatları, SWD,

buton ve röle sürüş sinyalleri gibi) düşük akım taşıdığından bu hatlarda 10 mil genişlik tercih

edilmiştir. Orta seviyede akım taşıyan hatlarda ısınmayı ve gerilim düşümünü sınırlamak

amacıyla 27.5 mil genişlik kullanılmıştır. 10A mertebesinde akımın aktığı kritik güç yollarında

ise tekil bir hat yerine doğrudan katı bakır poligon atanmıştır; bu sayede hem akım taşıma

kapasitesi klasik bir hatla kıyaslanamayacak ölçüde artırılmış hem de bakırın geniş yüzey alanı

sayesinde bir miktar pasif ısı yayılımı da sağlanmıştır.

Katlar arası bağlantı için kullanılan vialar, özellikle anahtarlama düğümlerinin ve güç

kademesi çıkış kondansatörlerinin yakınında sık aralıklarla yerleştirilerek üst katmandaki bakır

dökümler alt katmandaki GND düzlemine çok sayıda noktadan dikilmiştir. Bu, hem dönüş yolunun kısalmasını hem de yüksek frekanslı anahtarlama gürültüsünün katlar arasında halka

antene dönüşmesinin önüne geçilmesini sağlamıştır. Entegrelerin güç pinlerine yakın

konumlara yerleştirilen baypas kondansatörleri de yine kısa via ve kısa hat bağlantılarıyla

doğrudan GND düzlemine indirilmiştir.

Genel yerleşimde kart, işlevsel bloklara ayrılarak düzenlenmiştir. Güç girişinden

başlayan hat sırasıyla koruma elemanları (varistör, sigorta, termistör), ilk anahtarlamalı

dönüştürme kademesi (24V'tan 12V'a), ikinci kademe (12V'tan 5V'a) ve çıkış filtrelemesi

şeklinde ilerleyecek biçimde art arda konumlandırılmıştır; bu, güç akışının kart üzerinde

gereksiz çapraz geçişler yapmadan doğrusal bir hat izlemesini sağlamıştır. STM32

mikrodenetleyici, kristal osilatör ve analog ölçüm bloğu ise anahtarlama gürültüsünün en yoğun

olduğu güç hatlarından fiziksel olarak uzak tutulmuş, ayrı bir bölgede toplanmıştır. Bunun tek

istisnası, ölçüm amacıyla zorunlu olarak güç hattına yakın konumlanması gereken akım

sensörüdür; bu elemanın çıkışı da kart üzerinde mümkün olan en kısa yoldan op-amp girişine

yönlendirilerek gürültü alma riski azaltılmıştır. Kristal, MCU'nun osilatör pinlerine mümkün

olduğunca yakın yerleştirilmiş ve etrafı GND ile çevrelenmiştir.

Kartın kenar bölgelerine yerleştirilen montaj delikleri de yerleşimde işlevsel olarak

kullanılmıştır. Nextion ekranına giden haberleşme hattının karta giriş yaptığı konnektör, bu

montaj deliklerinin hemen yakınına konumlandırılmıştır; böylece dış birimden gelebilecek olası

hat gürültüsü, hassas kontrolcü bölgesine ulaşmadan önce en kısa yoldan şaseye aktarılıp

sönümlenmiştir. Genel olarak yerleşim, gürültüyü, ısınmayı ve kablo/hat karmaşasını aynı anda

en aza indirecek şekilde planlanmış; güç ve sinyal blokları birbirinden ayrılmış, kritik noktalar

bakır poligon ve via ile desteklenmiş, alt katman kesintisiz GND düzlemi olarak korunmuştur.

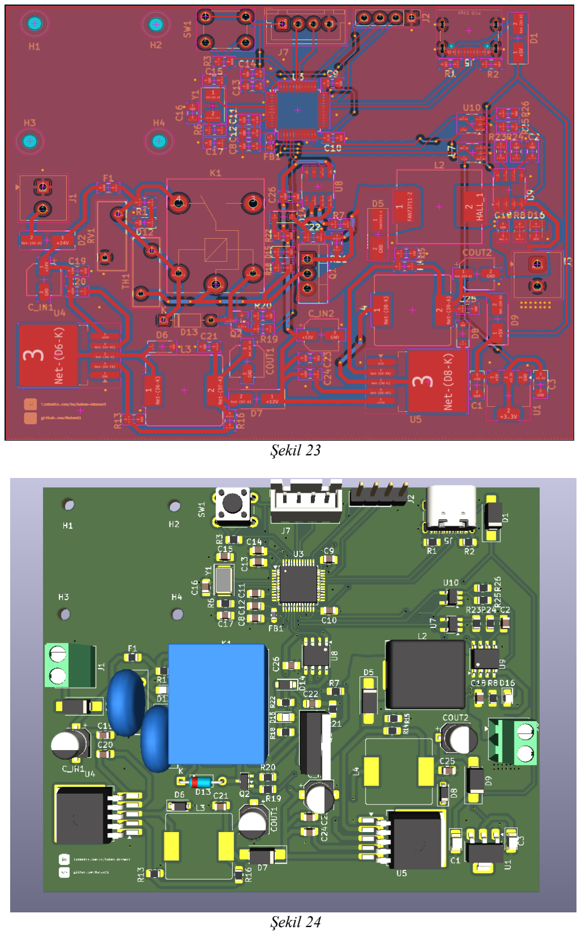
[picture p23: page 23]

Şekil 23

Şekil 24

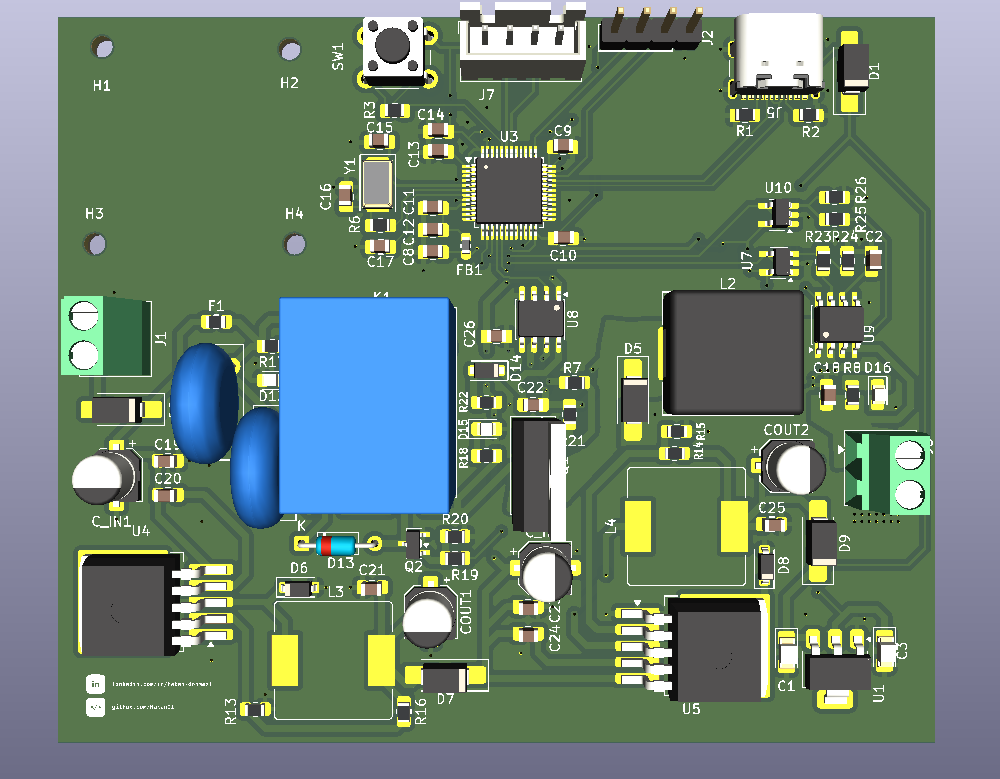
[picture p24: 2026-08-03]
schematic_pcb_3d/buck converter V6 3D.png

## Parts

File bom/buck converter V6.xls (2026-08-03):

Reference | Qty | Value | Footprint | PKG | MPN | Datasheet
C1 | 1 | 10uF | LED_SMD:LED_1206_3216Metric_Pad1.42x1.75mm_HandSolder | 1206 (3216 Metric) | CA45A010K476TA | https://mm.digikey.com/Volume0/opasdata/d220001/medias/docus/8469/3372_CA45A010K476TA.pdf
C2 | 1 | 1nF | Capacitor_SMD:C_0805_2012Metric_Pad1.18x1.45mm_HandSolder | 0805 (2012 Metric) | C0805C102K5RECAUTO | https://yageogroup.com/content/datasheet/asset/file/KEM_C1090_X7R_ESD
C3 | 1 | 22uF | LED_SMD:LED_1206_3216Metric_Pad1.42x1.75mm_HandSolder | 1206 (3216 Metric) | CA45A010K476TA | https://mm.digikey.com/Volume0/opasdata/d220001/medias/docus/8469/3372_CA45A010K476TA.pdf
C8,C12,C19,C20,C21,C22,C23,C24,C25,C26 | 10 | 1uF | Capacitor_SMD:C_0805_2012Metric_Pad1.18x1.45mm_HandSolder | 0805 (2012 Metric) | 0805B105K100CC | https://mm.digikey.com/Volume0/opasdata/d220001/medias/docus/5660/3372_0805B105K100CC.pdf
C9,C13,C14,C17 | 4 | 100nF | Capacitor_SMD:C_0805_2012Metric_Pad1.18x1.45mm_HandSolder | 0805 (2012 Metric) | 0805B104K201DC | https://mm.digikey.com/Volume0/opasdata/d220001/medias/docus/5491/0805B104K201DC.pdf
C10,C18 | 2 | 10uF | Capacitor_SMD:C_0805_2012Metric_Pad1.18x1.45mm_HandSolder | 0805 (2012 Metric) | 0805W106K6R3CC | https://mm.digikey.com/Volume0/opasdata/d220001/medias/docus/5660/3372_0805W106K6R3CC.pdf
C11 | 1 | 10nF | Capacitor_SMD:C_0805_2012Metric_Pad1.18x1.45mm_HandSolder | 0805 (2012 Metric) | 0805B103K251DC | https://mm.digikey.com/Volume0/opasdata/d220001/medias/docus/5491/0805B103K251DC.pdf
C15 | 1 | 5pF | Capacitor_SMD:C_0805_2012Metric_Pad1.18x1.45mm_HandSolder | 0805 (2012 Metric) | 0805N5R0C500AD | https://mm.digikey.com/Volume0/opasdata/d220001/medias/docus/5660/3372_0805N5R0C500AD.pdf
C16 | 1 | 25pF | Capacitor_SMD:C_0805_2012Metric_Pad1.18x1.45mm_HandSolder | 0805 | CC0805JRNPO9BN250 | https://www.yageo.com/en/Chart/Download/pdf/CC0805JRNPO9BN250
COUT1,COUT2 | 2 | 330uF | Capacitor_SMD:CP_Elec_5x5.8 | Radial, Can | EL1C471MP51011S | https://mm.digikey.com/Volume0/opasdata/d220001/medias/docus/2451/EL%20Series.pdf
C_IN1,C_IN2 | 2 | 220uF | Capacitor_SMD:CP_Elec_5x5.8 | Radial, Can | SL157M025HECRR | https://www.dropbox.com/scl/fi/0rn1da7eqo7zp5xobouq8/SL157M025HECRR.pdf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
D1,D2,D5,D7,D9 | 5 | D_Schottky | Diode_SMD:D_SMA_Handsoldering | DO-214AC (SMA) | SS54 | https://mm.digikey.com/Volume0/opasdata/d220001/medias/docus/6778/5399_SS54%20SMA.PDF
D6,D8 | 2 | D_Schottky | Diode_SMD:D_SOD-123 | SOD-123 | SD103AW | https://mm.digikey.com/Volume0/opasdata/d220001/medias/docus/6258/SD103AW100S040.pdf
D12,D15,D16 | 3 | LED | LED_SMD:LED_0805_2012Metric_Pad1.15x1.40mm_HandSolder | 0805 (2012 Metric) | LTST-C170KRKT | https://optoelectronics.liteon.com/upload/download/DS-22-99-0150/LTST-C170KRKT.pdf
D13 | 1 | 1N4148 | Diode_THT:D_DO-35_SOD27_P7.62mm_Horizontal | DO-35 | 1N4148 | https://assets.nexperia.com/documents/data-sheet/1N4148_1N4448.pdf
D14 | 1 | D | Diode_SMD:D_SOD-123F | SOD-123F | RS1MWF-7 | https://www.diodes.com/assets/Datasheets/RS1MWF.pdf
F1 | 1 | Fuse | Fuse:Fuse_0805_2012Metric_Pad1.15x1.40mm_HandSolder | 0805 (2012 Metric) | MFU0805FF05000P100 | https://www.vishay.com/docs/28747/mfuserie.pdf
FB1 | 1 | FerriteBead | Inductor_SMD:L_0603_1608Metric_Pad1.05x0.95mm_HandSolder | 0603 | MPZ1608S121ATDH5 | https://product.tdk.com/en/system/files
J1,J3 | 2 | Screw_Terminal_01x02 | TerminalBlock_Phoenix:TerminalBlock_Phoenix_MKDS-1-2-3.81_1x02_P3.81mm_Horizontal | Through Hole,P=5.08mm | JL127-50802G01 | https://www.lcsc.com/datasheet/C409161.pdf
J2 | 1 | Conn_01x04_Pin | Connector_PinHeader_2.54mm:PinHeader_1x04_P2.54mm_Vertical | Bulk | D01-9970442 | https://content.harwin.com/m/e0b6c35948424a73/original/DRG-00097-Technical-Drawing-Datasheet-D01-997-pdf.pdf
J5 | 1 | USB_C_Receptacle_USB2.0_16P | Connector_USB:USB_C_Receptacle_GCT_USB4105-xx-A_16P_TopMnt_Horizontal | SMD | USB4105-GF-A | https://www.usb.org/sites/default/files/documents/usb_type-c.zip
J7 | 1 | Conn_01x04_Pin | Connector_JST:JST_XH_B4B-XH-A_1x04_P2.50mm_Vertical | Bulk | B4B-XH-A | https://www.jst-mfg.com/product/pdf/eng/eXH.pdf
K1 | 1 | SANYOU_SRD_Form_C | Relay_THT:Relay_SPDT_SANYOU_SRD_Series_Form_C | Through Hole,19.2x15.6mm | SRD-24VDC-SL-C | https://www.lcsc.com/datasheet/C15840.pdf
L2 | 1 | 33uH | Inductor_SMD:L_Sunlord_MWSA1205S-330 | SMD | 125CDMCCDS-330MC | https://products.sumida.com/products/pdf/125CDMCCDS%20(en).pdf
L3,L4 | 2 | 47uH | Inductor_SMD:L_Bourns_SRR1210A | Tape & Reel | SRR1210-470M | https://www.bourns.com/docs/Product-Datasheets/SRR1210.pdf
Q1 | 1 | Q_NMOS_GDS | Package_TO_SOT_THT:TO-220-3_Vertical | TO-220-3 | AUIRL3705N | https://rocelec.widen.net/view/pdf/ygqcefgxtp/IRSDS11401-1.pdf?t.download=true&u=5oefqw
Q2 | 1 | BC817 | Package_TO_SOT_SMD:SOT-23 | SOT-23 | BC817 | https://www.onsemi.com/pub/Collateral/BC818-D.pdf
R1,R2 | 2 | 5.1K | Resistor_SMD:R_0805_2012Metric_Pad1.20x1.40mm_HandSolder | 0805 | RM10J512CT | https://calchip.com/wp-content/uploads/2025/05/RMSERIES-052225.pdf
R3,R14,R20,R21,R23 | 5 | 10K | Resistor_SMD:R_0805_2012Metric_Pad1.20x1.40mm_HandSolder | 0805 | RM10J103CT | https://calchip.com/wp-content/uploads/2025/05/RMSERIES-052225.pdf
R6,R8 | 2 | 330 | Resistor_SMD:R_0805_2012Metric_Pad1.20x1.40mm_HandSolder | 0805 | RM10J331CT | https://calchip.com/wp-content/uploads/2025/05/RMSERIES-052225.pdf
R7,R22 | 2 | 10 | Resistor_SMD:R_0805_2012Metric_Pad1.20x1.40mm_HandSolder | 0805 | ERJ-6ENF10R0V | https://industrial.panasonic.com/cdbs/www-data/pdf/RDA0000/AOA0000C304.pdf
R13,R19 | 2 | 1.5K | Resistor_SMD:R_0805_2012Metric_Pad1.20x1.40mm_HandSolder | 0805 | RM10F1501CT | https://calchip.com/wp-content/uploads/2025/05/RMSERIES-052225.pdf
R15,R17,R18 | 3 | 3.3K | Resistor_SMD:R_0805_2012Metric_Pad1.20x1.40mm_HandSolder | 0805 | RM10J332CT | https://calchip.com/wp-content/uploads/2025/05/RMSERIES-052225.pdf
R16 | 1 | 13K | Resistor_SMD:R_0805_2012Metric_Pad1.20x1.40mm_HandSolder | 0805 | RM10J133CT | https://calchip.com/wp-content/uploads/2025/05/RMSERIES-052225.pdf
R24,R25,R26 | 3 | 20K | Resistor_SMD:R_0805_2012Metric_Pad1.20x1.40mm_HandSolder | 0805 | ERJ-6ENF2002V | https://industrial.panasonic.com/cdbs/www-data/pdf/RDA0000/AOA0000C304.pdf
RV1 | 1 | Varistor | Varistor:RV_Disc_D12mm_W4.6mm_P7.5mm | Disc 10mm | 10D390K | https://www.ruilon.com.cn/Uploads/pdf/10d%20series_a2.pdf
SW1 | 1 | SW_Push | Button_Switch_THT:SW_PUSH_6mm | SMD-4P,6x6mm | ZX-QC66-8.5TP | https://www.lcsc.com/datasheet/C7470159.pdf
TH1 | 1 | Thermistor | Varistor:RV_Disc_D12mm_W4.4mm_P7.5mm | Through Hole,P=7.5mm | SURGING 10D-11 | https://www.lcsc.com/datasheet/C2839614.pdf
U1 | 1 | AMS1117-3.3 | Package_TO_SOT_SMD:SOT-223-3_TabPin2 | SOT-223-3 | AMS1117-3.3 | http://www.advanced-monolithic.com/pdf/ds1117.pdf
U3 | 1 | STM32F103C8Tx | Package_QFP:LQFP-48_7x7mm_P0.5mm | 48-LQFP | STM32F103C8T6 | https://www.st.com/resource/en/datasheet/stm32f103c8.pdf
U4,U5 | 2 | XL4015 | Package_TO_SOT_SMD:TO-263-5_TabPin3 | TO-263-5 | XL4015E1 | https://www.lcsc.com/datasheet/C51661.pdf
U7,U10 | 2 | MCP6001-OT | Package_TO_SOT_SMD:SOT-23-5_HandSoldering | SOT-23-5 | MCP6001T-I/OT | https://ww1.microchip.com/downloads/en/DeviceDoc/MCP6001-1R-1U-2-4-1-MHz-Low-Power-Op-Amp-DS20001733L.pdf
U8 | 1 | FAN7371 | Package_SO:SOIC-8_3.9x4.9mm_P1.27mm | 8-SOIC | FAN73711MX | https://www.onsemi.com/pub/Collateral/FAN7371-D.pdf
U9 | 1 | ACS712xLCTR-20A | Package_SO:SOIC-8_3.9x4.9mm_P1.27mm | 8-SOIC | ACS712ELCTR-20A-T | http://www.allegromicro.com/~/media/Files/Datasheets/ACS712-Datasheet.ashx?la=en
Y1 | 1 | Crystal | Crystal:Crystal_SMD_5032-2Pin_5.0x3.2mm | 2-SMD (5x3.2) | 0153G2-8.000F22DTNLK | https://www.hcixtal.com/uploads/44524/files/0153G2.pdf

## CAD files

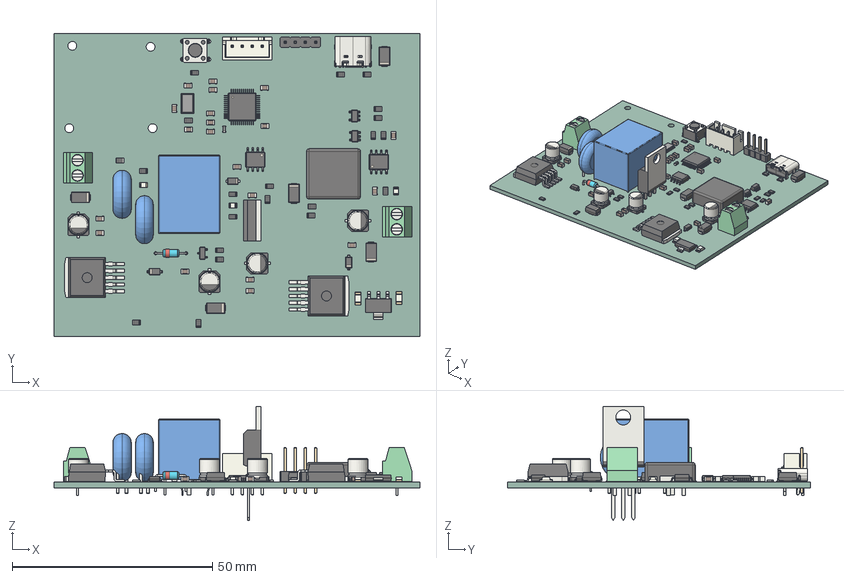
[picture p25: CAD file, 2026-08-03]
STEP FILES/.step
91.4 x 75.6 x 28.5 mm
D_SOD-123 x 2
CP_Elec_5x58 x 4
C_0805_2012Metric x 20
LED_0805_2012Metric x 3
Relay_SPDT_SANYOU_SRD_Series_Form_C
R_0805_2012Metric x 20
Fuse_0805_2012Metric
TerminalBlock_Phoenix_MKDS-1-2-3.81_1x02_P3.81mm_Horizontal x 2
L_0603_1608Metric
a87d2c1a-8551-11ed-a139-00155d22e2d7_part
a87d2e7c-8551-11ed-a139-00155d22e2d7_part
a87d300c-8551-11ed-a139-00155d22e2d7_part
PinHeader_1x04_P254mm_Vertical
SOIC-8_3.9x4.9mm_P1.27mm x 2
JST_B4B_XH_A
D_DO-35_SOD27_P7.62mm_Horizontal
D_SMA x 5
SOT-23-5 x 2
SOT-23
RV_Disc_D12mm_W46mm_P75mm
SW_PUSH_6mm
RV_Disc_D12mm_W44mm_P75mm
LED_1206_3216Metric x 2
USB_C_Receptacle_16P_TopMnt_Horizontal_GCT_USB4105-xx-A
LQFP-48_7x7mm_P0.5mm
D_SOD_123F
a648ce37-9c39-11ed-93f0-dde97e994e83_part x 2
a648ce38-9c39-11ed-93f0-dde97e994e83_part x 2
a648ce39-9c39-11ed-93f0-dde97e994e83_part x 2
SOT-223
TO-220-3_Vertical
Crystal_SMD_5032-2Pin_5.0x3.2mm
buck converter V6_PCB

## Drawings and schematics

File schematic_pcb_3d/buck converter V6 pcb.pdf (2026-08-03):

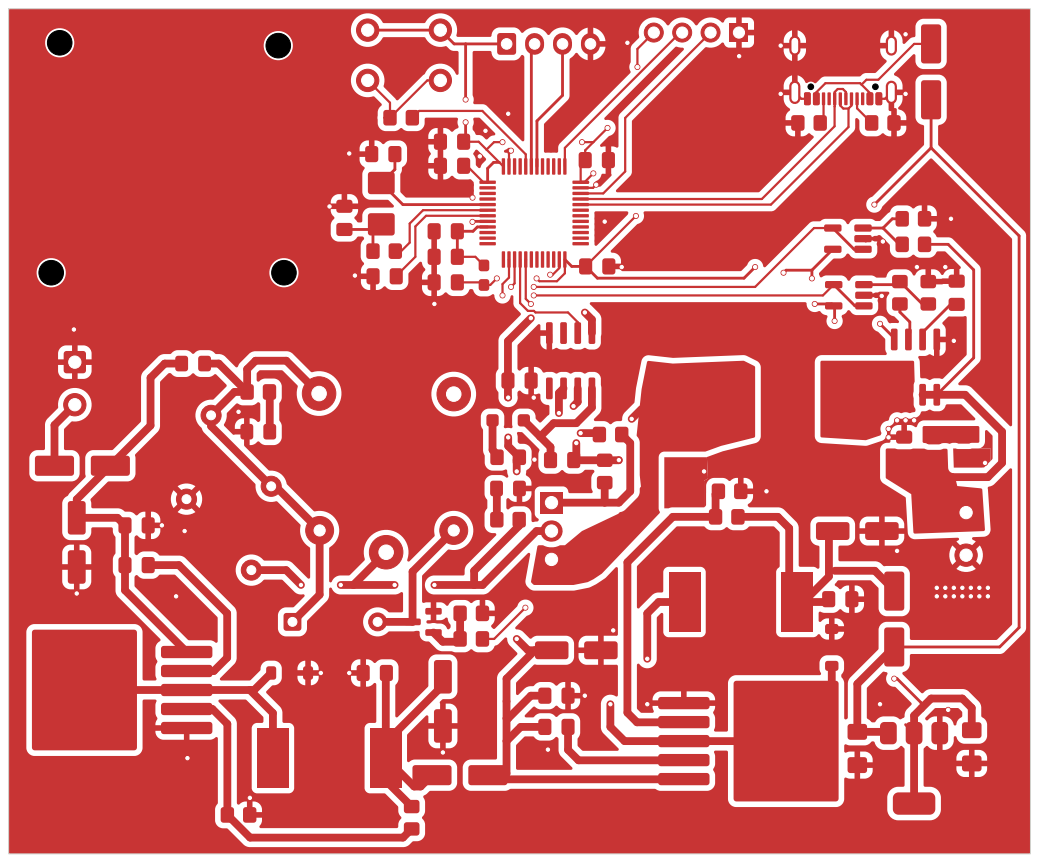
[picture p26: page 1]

Size: A4 | Rev:
KiCad E.D.A. 10.0.4 | Id: 1/3

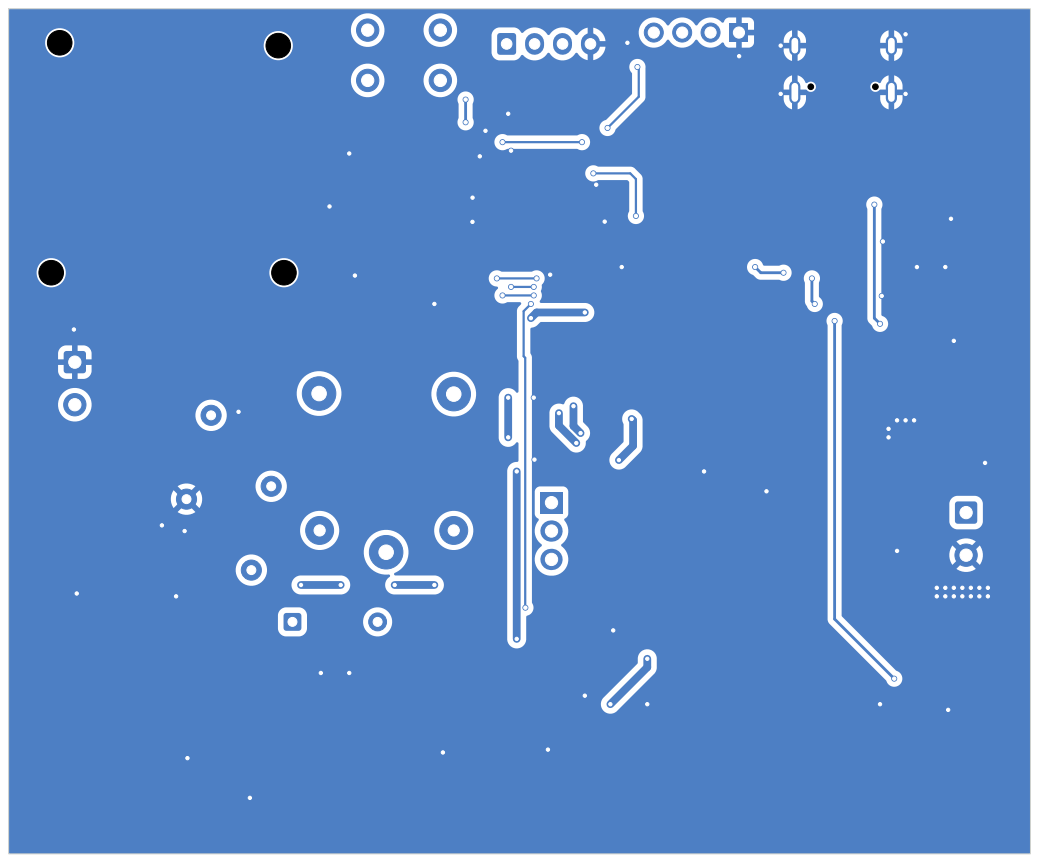
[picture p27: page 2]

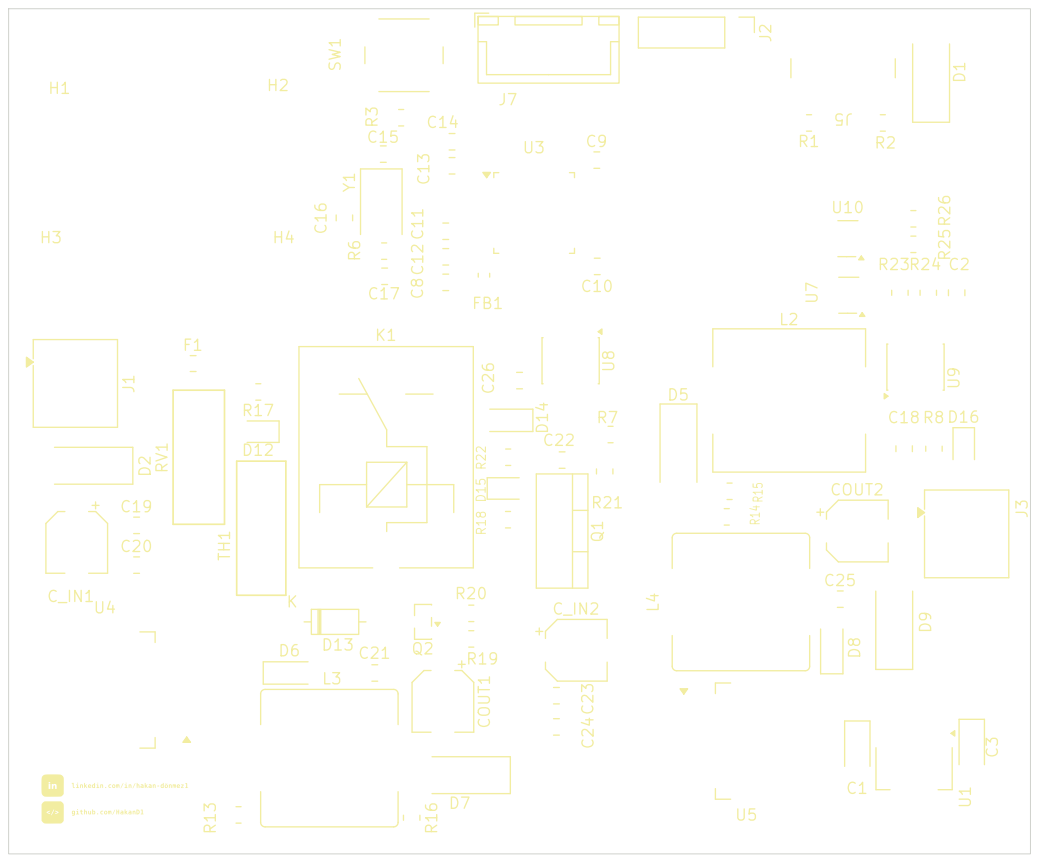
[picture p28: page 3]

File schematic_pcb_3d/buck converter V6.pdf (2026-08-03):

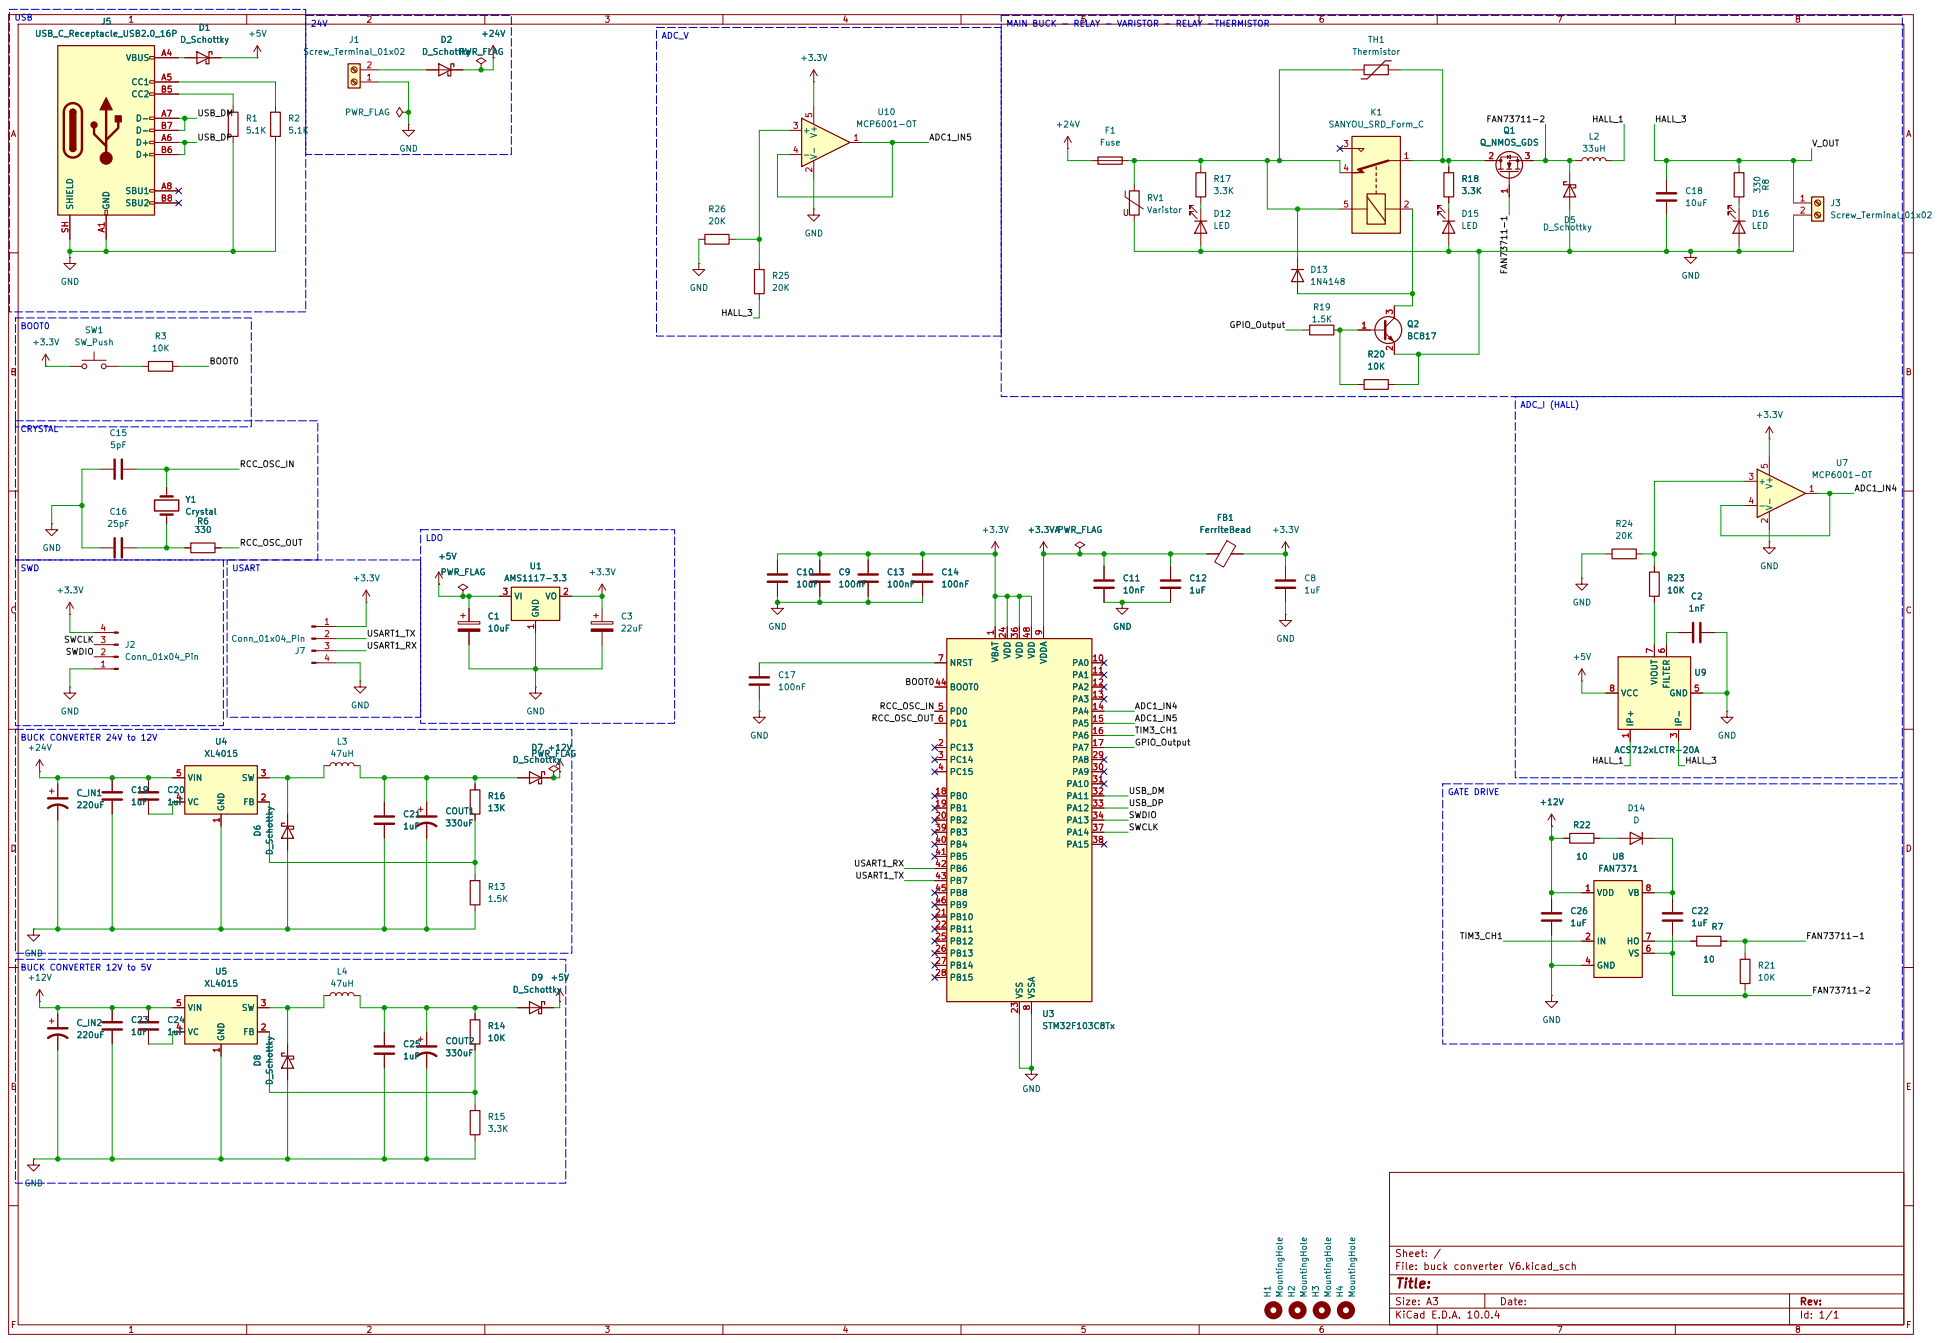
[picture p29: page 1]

TIM3_CH1 BUCK CONVERTER 24V to 12V BUCK CONVERTER 12V to 5V SWD

Size: A3 | Rev:
KiCad E.D.A. 10.0.4 | Id: 1/1 | F Date:

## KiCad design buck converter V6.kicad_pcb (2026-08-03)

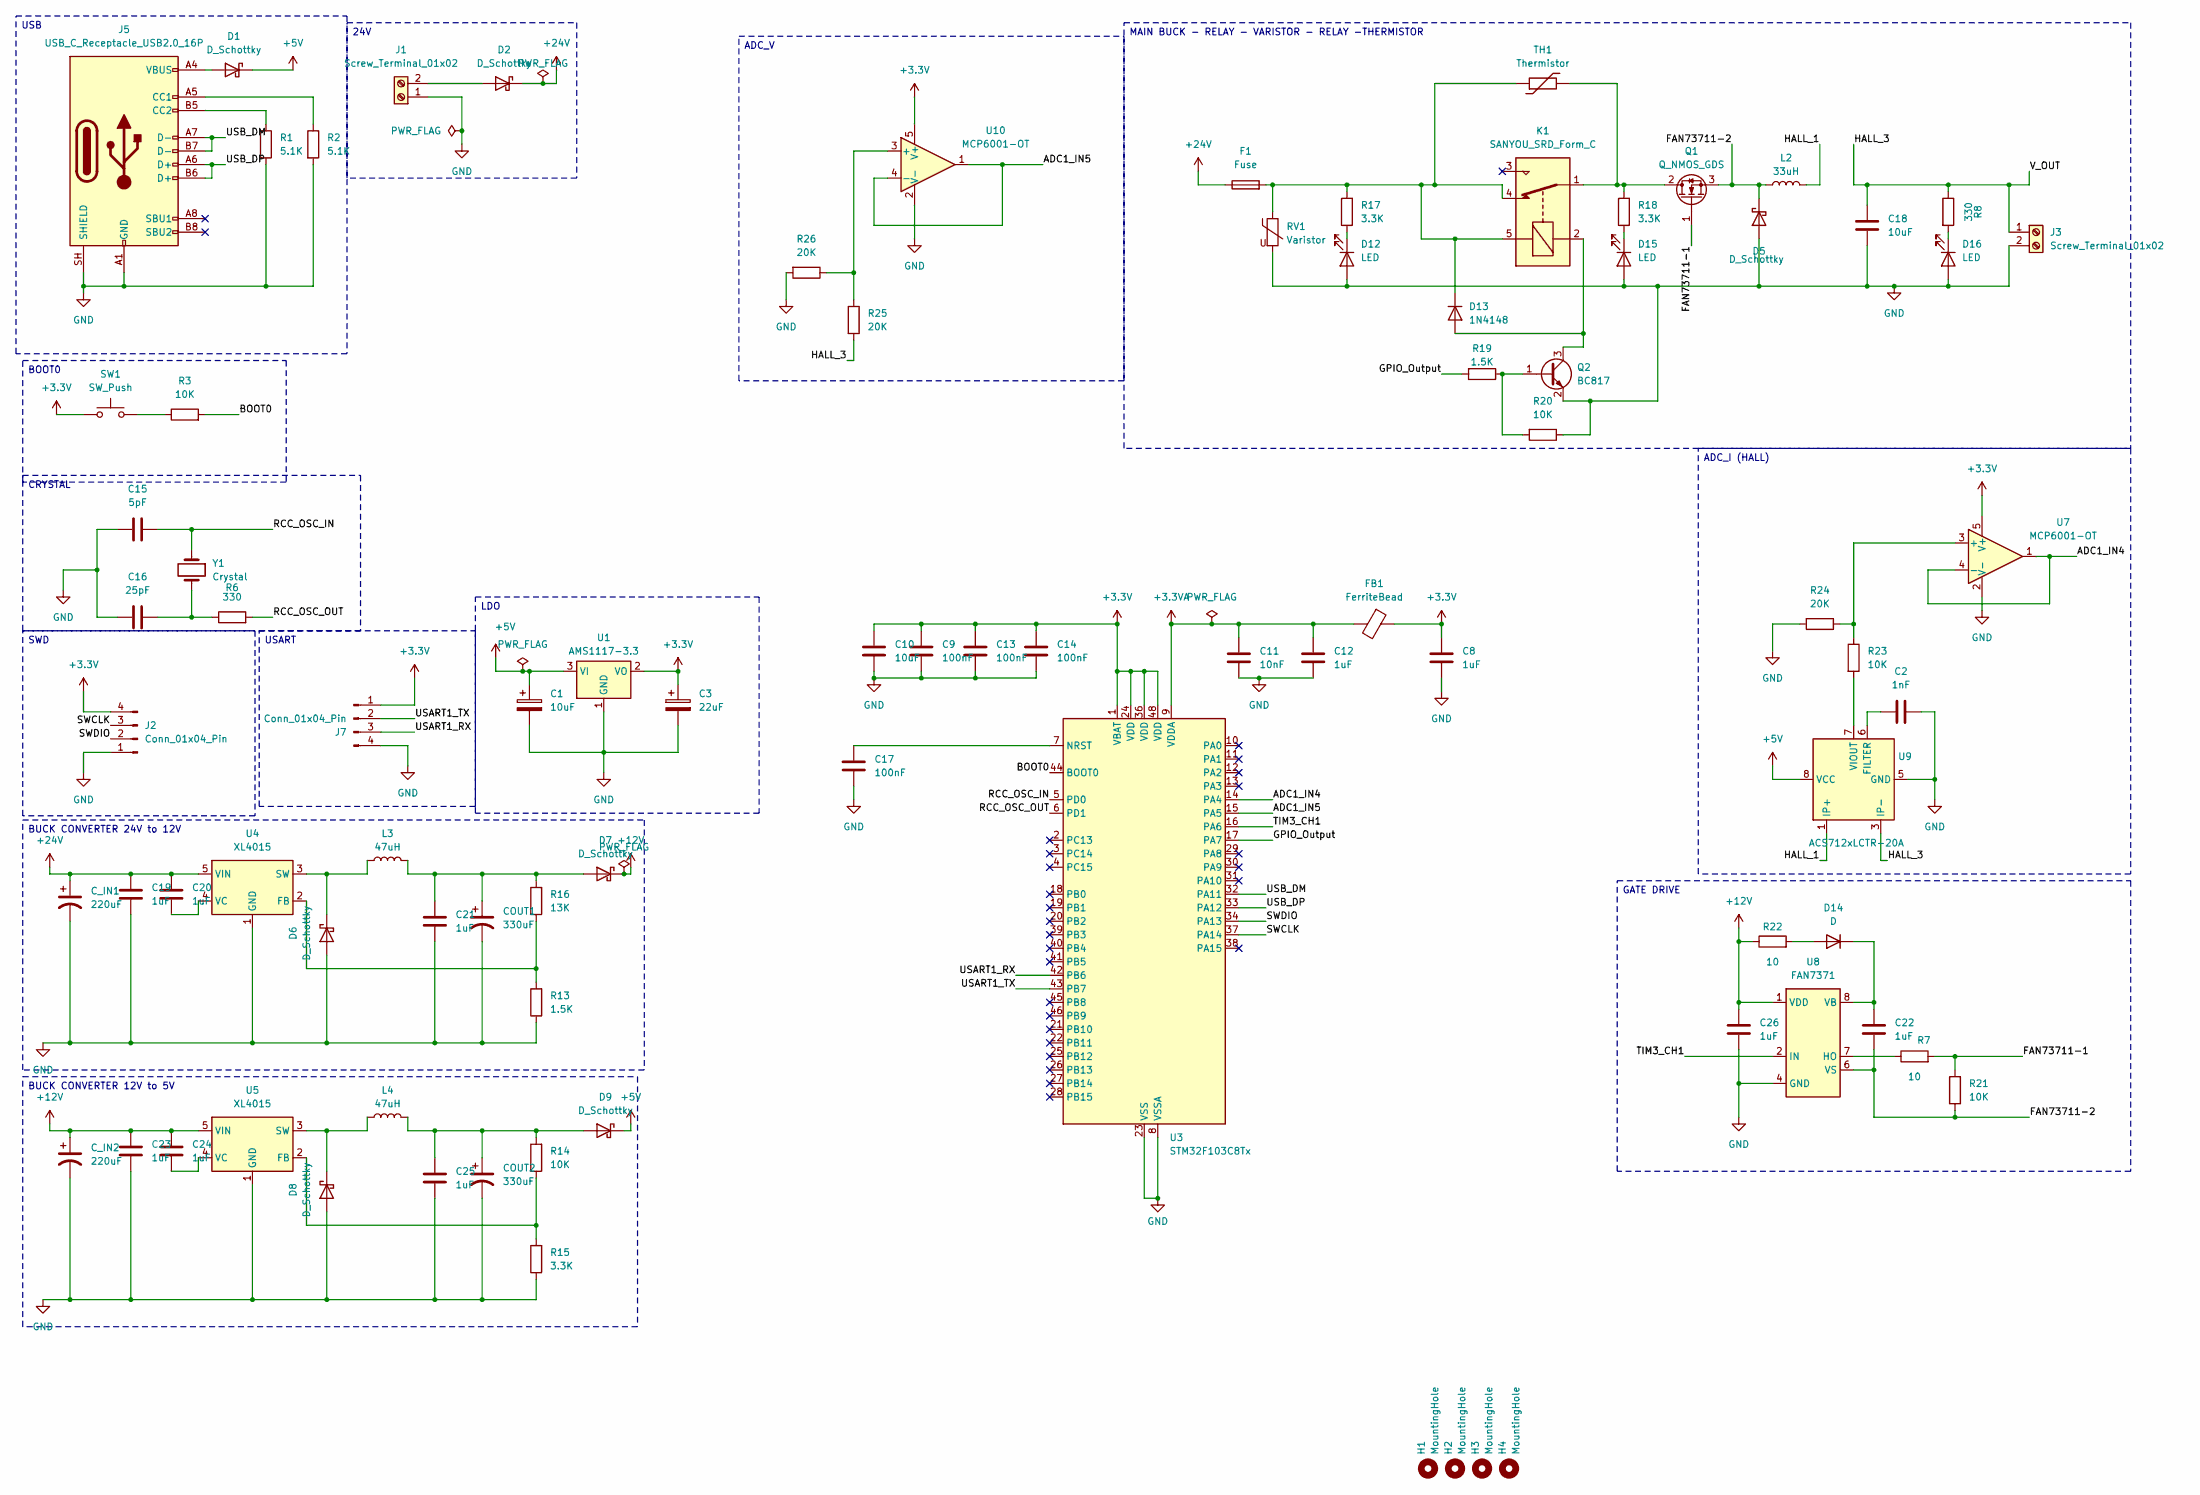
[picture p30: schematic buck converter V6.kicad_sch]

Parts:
C1: 10uF; LED_1206_3216Metric_Pad1.42x1.75mm_HandSolder; MPN CA45A010K476TA
C2: 1nF; C_0805_2012Metric_Pad1.18x1.45mm_HandSolder; MPN C0805C102K5RECAUTO
C3: 22uF; LED_1206_3216Metric_Pad1.42x1.75mm_HandSolder; MPN CA45A010K476TA
C8, C12, C19, C20, C21, C22, C23, C24, C25, C26: 1uF; C_0805_2012Metric_Pad1.18x1.45mm_HandSolder; MPN 0805B105K100CC
C9, C13, C14, C17: 100nF; C_0805_2012Metric_Pad1.18x1.45mm_HandSolder; MPN 0805B104K201DC
C10, C18: 10uF; C_0805_2012Metric_Pad1.18x1.45mm_HandSolder; MPN 0805W106K6R3CC
C11: 10nF; C_0805_2012Metric_Pad1.18x1.45mm_HandSolder; MPN 0805B103K251DC
C15: 5pF; C_0805_2012Metric_Pad1.18x1.45mm_HandSolder; MPN 0805N5R0C500AD
C16: 25pF; C_0805_2012Metric_Pad1.18x1.45mm_HandSolder; MPN CC0805JRNPO9BN250
COUT1, COUT2: 330uF; CP_Elec_5x5.8; MPN EL1C471MP51011S
C_IN1, C_IN2: 220uF; CP_Elec_5x5.8; MPN SL157M025HECRR
D1, D2, D5, D7, D9: D_Schottky; D_SMA_Handsoldering; MPN SS54
D6, D8: D_Schottky; D_SOD-123; MPN SD103AW
D12, D15, D16: LED; LED_0805_2012Metric_Pad1.15x1.40mm_HandSolder; MPN LTST-C170KRKT
D13: 1N4148; D_DO-35_SOD27_P7.62mm_Horizontal; MPN 1N4148
D14: D; D_SOD-123F; MPN RS1MWF-7
F1: Fuse; Fuse_0805_2012Metric_Pad1.15x1.40mm_HandSolder; MPN MFU0805FF05000P100
FB1: FerriteBead; L_0603_1608Metric_Pad1.05x0.95mm_HandSolder; MPN MPZ1608S121ATDH5
H1, H2, H3, H4: MountingHole; MountingHole_2.2mm_M2
J1, J3: Screw_Terminal_01x02; TerminalBlock_Phoenix_MKDS-1-2-3.81_1x02_P3.81mm_Horizontal; MPN JL127-50802G01
J2: Conn_01x04_Pin; PinHeader_1x04_P2.54mm_Vertical; MPN D01-9970442
J5: USB_C_Receptacle_USB2.0_16P; USB_C_Receptacle_GCT_USB4105-xx-A_16P_TopMnt_Horizontal; MPN USB4105-GF-A
J7: Conn_01x04_Pin; JST_XH_B4B-XH-A_1x04_P2.50mm_Vertical; MPN B4B-XH-A
K1: SANYOU_SRD_Form_C; Relay_SPDT_SANYOU_SRD_Series_Form_C; MPN SRD-24VDC-SL-C
L2: 33uH; L_Sunlord_MWSA1205S-330; MPN 125CDMCCDS-330MC
L3, L4: 47uH; L_Bourns_SRR1210A; MPN SRR1210-470M
Q1: Q_NMOS_GDS; TO-220-3_Vertical; MPN AUIRL3705N
Q2: BC817; SOT-23; MPN BC817
R1, R2: 5.1K; R_0805_2012Metric_Pad1.20x1.40mm_HandSolder; MPN RM10J512CT
R3, R14, R20, R21, R23: 10K; R_0805_2012Metric_Pad1.20x1.40mm_HandSolder; MPN RM10J103CT
R6, R8: 330; R_0805_2012Metric_Pad1.20x1.40mm_HandSolder; MPN RM10J331CT
R7, R22: 10; R_0805_2012Metric_Pad1.20x1.40mm_HandSolder; MPN ERJ-6ENF10R0V
R13, R19: 1.5K; R_0805_2012Metric_Pad1.20x1.40mm_HandSolder; MPN RM10F1501CT
R15, R17, R18: 3.3K; R_0805_2012Metric_Pad1.20x1.40mm_HandSolder; MPN RM10J332CT
R16: 13K; R_0805_2012Metric_Pad1.20x1.40mm_HandSolder; MPN RM10J133CT
R24, R25, R26: 20K; R_0805_2012Metric_Pad1.20x1.40mm_HandSolder; MPN ERJ-6ENF2002V
RV1: Varistor; RV_Disc_D12mm_W4.6mm_P7.5mm; MPN 10D390K
SW1: SW_Push; SW_PUSH_6mm; MPN ZX-QC66-8.5TP
TH1: Thermistor; RV_Disc_D12mm_W4.4mm_P7.5mm; MPN SURGING 10D-11
U1: AMS1117-3.3; SOT-223-3_TabPin2; MPN AMS1117-3.3
U3: STM32F103C8Tx; LQFP-48_7x7mm_P0.5mm; MPN STM32F103C8T6
U4, U5: XL4015; TO-263-5_TabPin3; MPN XL4015E1
U7, U10: MCP6001-OT; SOT-23-5_HandSoldering; MPN MCP6001T-I/OT
U8: FAN7371; SOIC-8_3.9x4.9mm_P1.27mm; MPN FAN73711MX
U9: ACS712xLCTR-20A; SOIC-8_3.9x4.9mm_P1.27mm; MPN ACS712ELCTR-20A-T
Y1: Crystal; Crystal_SMD_5032-2Pin_5.0x3.2mm; MPN 0153G2-8.000F22DTNLK

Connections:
+3.3V: C3.1, C8.1, C9.1, C10.1, C13.1, C14.1, FB1.1, J2.4, J7.1, SW1.1, U1.2 (VO), U3.1 (VBAT), U3.24 (VDD), U3.36 (VDD), U3.48 (VDD), U7.5 (V+), U10.5 (V+)
+3.3VA: C11.1, C12.1, FB1.2, U3.9 (VDDA)
+5V: C1.1, D1.1 (K), D9.1 (K), U1.3 (VI), U9.8 (VCC)
+12V: C23.1, C24.1, C26.1, C_IN2.1, D7.1 (K), R22.1, U5.5 (VIN), U8.1 (VDD)
+24V: C19.1, C20.1, C_IN1.1, D2.1 (K), F1.1, U4.5 (VIN)
/ADC1_IN4: U3.14 (PA4), U7.1, U7.4 (-)
/ADC1_IN5: U3.15 (PA5), U10.1, U10.4 (-)
/BOOT0: R3.2, U3.44 (BOOT0)
/FAN73711-1: Q1.1 (G), R7.2, R21.2
/FAN73711-2: C22.2, D5.1 (K), L2.1, Q1.3 (S), R21.1, U8.6 (VS)
/GPIO_Output: R19.2, U3.17 (PA7)
/HALL_1: L2.2, U9.1 (IP+), U9.2 (IP+)
/HALL_3: C18.1, J3.1, R8.1, R25.2, U9.3 (IP-), U9.4 (IP-)
/RCC_OSC_IN: C15.2, U3.5 (PD0), Y1.1
/RCC_OSC_OUT: R6.2, U3.6 (PD1)
/SWCLK: J2.3, U3.37 (PA14)
/SWDIO: J2.2, U3.34 (PA13)
/TIM3_CH1: U3.16 (PA6), U8.2 (IN)
/USART1_RX: J7.3, U3.42 (PB6)
/USART1_TX: J7.2, U3.43 (PB7)
/USB_DM: J5.A7 (D-), J5.B7 (D-), U3.32 (PA11)
/USB_DP: J5.A6 (D+), J5.B6 (D+), U3.33 (PA12)
GND: C1.2, C2.2, C3.2, C8.2, C9.2, C10.2, C11.2, C12.2, C13.2, C14.2, C15.1, C16.1, C17.2, C18.2, C19.2, C21.2, C23.2, C25.2, C26.2, COUT1.2, COUT2.2, C_IN1.2, C_IN2.2, D5.2 (A), D6.2 (A), D8.2 (A), D12.2 (A), D15.2 (A), D16.2 (A), J1.1, J2.1, J3.2, J5.A1 (GND), J5.A12 (GND), J5.B1 (GND), J5.B12 (GND), J5.SH (SHIELD), J7.4, Q2.2 (E), R1.2, R2.2, R13.1, R15.1, R20.1, R24.2, R26.2, RV1.2, U1.1 (GND), U3.8 (VSSA), U3.23 (VSS), U3.35 (VSS), U3.47 (VSS), U4.1 (GND), U5.1 (GND), U7.2 (V-), U8.4 (GND), U9.5 (GND), U10.2 (V-)
unnamed: C16.2, R6.1, Y1.2
unnamed: D1.2 (A), J5.A4 (VBUS), J5.A9 (VBUS), J5.B4 (VBUS), J5.B9 (VBUS)
unnamed: D2.2 (A), J1.2
unnamed: D6.1 (K), L3.1, U4.3 (SW)
unnamed: C21.1, COUT1.1, D7.2 (A), L3.2, R16.2
unnamed: D8.1 (K), L4.1, U5.3 (SW)
unnamed: C25.1, COUT2.1, D9.2 (A), L4.2, R14.2
unnamed: D12.1 (K), R17.1
unnamed: D13.2 (A), K1.2, Q2.3 (C)
unnamed: D13.1 (K), F1.2, K1.4, K1.5, R17.2, RV1.1, TH1.1
unnamed: D14.2 (A), R22.2
unnamed: C22.1, D14.1 (K), U8.8 (VB)
unnamed: D15.1 (K), R18.1
unnamed: D16.1 (K), R8.2
unnamed: J5.A5 (CC1), R2.1
unnamed: J5.B5 (CC2), R1.1
unnamed: K1.1, Q1.2 (D), R18.2, TH1.2
unnamed: Q2.1 (B), R19.1, R20.2
unnamed: R3.1, SW1.2
unnamed: C17.1, U3.7 (NRST)
unnamed: R13.2, R16.1, U4.2 (FB)
unnamed: C20.2, U4.4 (VC)
unnamed: R14.1, R15.2, U5.2 (FB)
unnamed: C24.2, U5.4 (VC)
unnamed: R23.1, R24.1, U7.3 (+)
unnamed: R7.1, U8.7 (HO)
unnamed: C2.1, U9.6 (FILTER)
unnamed: R23.2, U9.7 (VIOUT)
unnamed: R25.1, R26.1, U10.3 (+)

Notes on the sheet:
ADC_V
USB
LDO
BOOT0
SWD
GATE DRIVE
24V
BUCK CONVERTER 24V to 12V
BUCK CONVERTER 12V to 5V
USART
MAIN BUCK - RELAY - VARISTOR - RELAY -THERMISTOR
CRYSTAL
ADC_I (HALL)

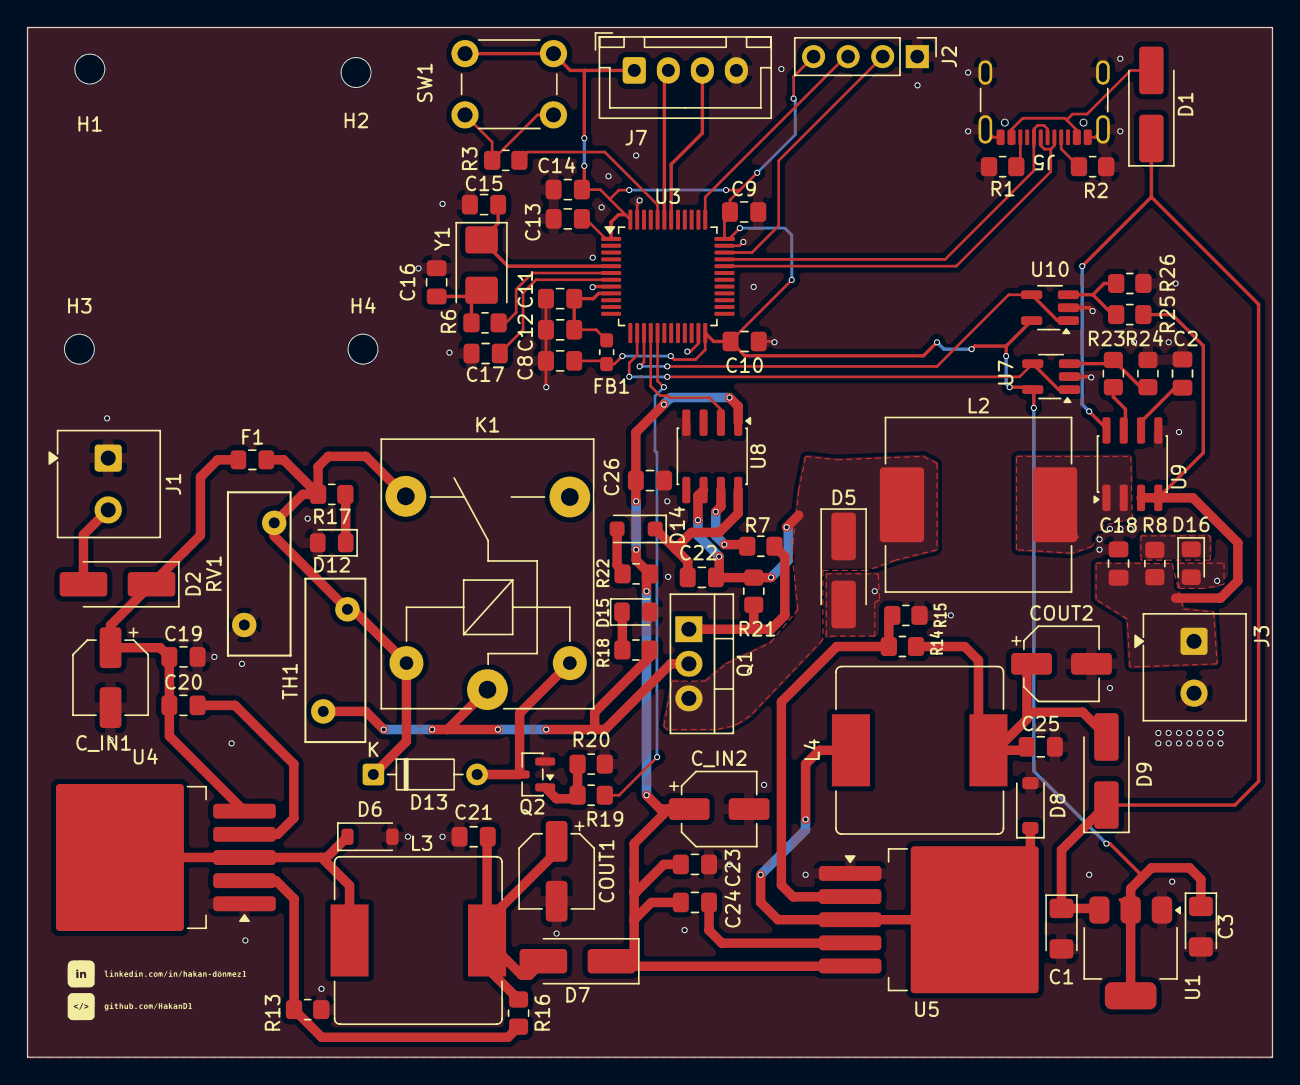
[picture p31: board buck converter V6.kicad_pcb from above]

Board: 2 copper layers, 91.4 x 75.6 mm, 88 parts (0 on the bottom side), 52 nets.

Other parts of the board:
.: LOGO; logo1

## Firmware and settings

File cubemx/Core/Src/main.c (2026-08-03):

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
/* Includes ------------------------------------------------------------------*/
#include "main.h"
#include "adc.h"
#include "dma.h"
#include "i2c.h"
#include "spi.h"
#include "tim.h"
#include "usart.h"
#include "usb.h"
#include "gpio.h"

/* USER CODE BEGIN Includes */
#include <stdio.h>
#include <string.h>
#include <stdlib.h>
/* USER CODE END Includes */

/* USER CODE BEGIN PV */

/* Sensor and reading variables */
uint16_t adc_buffer[2];
float out_voltage = 0.0;
float out_current = 0.0;
float raw_voltage = 0.0;
float raw_current = 0.0;

/* System and Control Variables */
uint8_t System_Mode = 1;  /* 0: Manual, 1: PI_V, 2: PI_I */
uint8_t Relay_State = 0;  /* 0: OFF, 1: ON */
int Duty_Cycle = 0;       /* 0 - 399 */
float I_Limit = 12.0;     /* OCP Limit */

/* Voltage PI Parameters */
float V_Ref = 0.0;
float Kp_V = 0.0;
float Ki_V = 0.0;
float V_Cal = 1.0;
float V_Offset = 0.0;
float integral_V = 0.0;

/* Current PI Parameters */
float I_Ref = 0.0;
float Kp_I = 0.0;
float Ki_I = 0.0;
float I_Cal = 1.0;
float I_Offset = 0.0;
float integral_I = 0.0;

/* Manual Mode Parameters */
float M_Offset = 0.0;

/* UART RX Buffers */
uint8_t rx_byte;
char rx_line_buffer[64];
uint8_t rx_line_index = 0;
volatile uint8_t rx_line_ready = 0;
char rx_line_copy[64];
/* USER CODE END PV */

void SystemClock_Config(void);
/* USER CODE BEGIN PFP */
void Process_Nextion_Command(char *line);
/* USER CODE END PFP */

/**
  * @brief  The application entry point.
  * @retval int
  */
int main(void)
{
  /* MCU Configuration--------------------------------------------------------*/
  HAL_Init();
  SystemClock_Config();

  /* Initialize all configured peripherals */
  MX_GPIO_Init();
  MX_DMA_Init();
  MX_ADC1_Init();
  MX_I2C2_Init();
  MX_SPI1_Init();
  MX_USART1_UART_Init();
  MX_USB_PCD_Init();
  MX_TIM3_Init();

  /* USER CODE BEGIN 2 */
  HAL_ADC_Start_DMA(&hadc1, (uint32_t*)adc_buffer, 2);
  HAL_TIM_PWM_Start(&htim3, TIM_CHANNEL_1);

  HAL_NVIC_SetPriority(USART1_IRQn, 0, 0);
  HAL_NVIC_EnableIRQ(USART1_IRQn);

  /* Start UART Interrupt */
  HAL_UART_Receive_IT(&huart1, &rx_byte, 1);
  /* USER CODE END 2 */

  /* Infinite loop */
  /* USER CODE BEGIN WHILE */
  while (1)
  {
    /* ADC Reading and Calibration Block */
    float pin_voltage_v = ((float)adc_buffer[1] / 4095.0) * 3.3;
    float pin_voltage_i = ((float)adc_buffer[0] / 4095.0) * 3.3;

    raw_voltage = pin_voltage_v * 2.0;
    float sensor_viout = pin_voltage_i * 1.5;
    raw_current = (sensor_viout - 2.5) * 10.0;

    out_voltage = (raw_voltage * V_Cal) + V_Offset;
    out_current = (raw_current * I_Cal) + I_Offset;

    /* UART Parsing Block */
    if (rx_line_ready)
    {
        Process_Nextion_Command(rx_line_copy);
        rx_line_ready = 0;
    }

    /* OCP (Over Current Protection) Block */
    if (out_current > I_Limit)
    {
        Relay_State = 0;
        Duty_Cycle = 0;
    }

    /* Control Algorithms Block (PI & Manual) */
    if (Relay_State == 0)
    {
        /* System OFF: Reset PWM and Integrals */
        __HAL_TIM_SET_COMPARE(&htim3, TIM_CHANNEL_1, 0);
        integral_V = 0.0;
        integral_I = 0.0;
    }
    else
    {
        /* Voltage PI Control */
        if (System_Mode == 1)
        {
            float error = V_Ref - out_voltage;
            integral_V += (Ki_V * error);

            if (integral_V > 399.0) integral_V = 399.0;
            if (integral_V < 0.0) integral_V = 0.0;

            float calc_duty = (Kp_V * error) + integral_V;

            if (calc_duty > 399.0) calc_duty = 399.0;
            if (calc_duty < 0.0) calc_duty = 0.0;

            __HAL_TIM_SET_COMPARE(&htim3, TIM_CHANNEL_1, (uint32_t)calc_duty);
        }
        /* Current PI Control */
        else if (System_Mode == 2)
        {
            float error = I_Ref - out_current;
            integral_I += (Ki_I * error);

            if (integral_I > 399.0) integral_I = 399.0;
            if (integral_I < 0.0) integral_I = 0.0;

            float calc_duty = (Kp_I * error) + integral_I;

            if (calc_duty > 399.0) calc_duty = 399.0;
            if (calc_duty < 0.0) calc_duty = 0.0;

            __HAL_TIM_SET_COMPARE(&htim3, TIM_CHANNEL_1, (uint32_t)calc_duty);
        }
        /* Manual Duty Control */
        else if (System_Mode == 0)
        {
            if (Duty_Cycle > 399) Duty_Cycle = 399;
            if (Duty_Cycle < 0) Duty_Cycle = 0;
            __HAL_TIM_SET_COMPARE(&htim3, TIM_CHANNEL_1, (uint32_t)Duty_Cycle);
        }
    }

    /* Nextion Telemetry Update Block */
    static uint32_t last_uart_time = 0;
    if (HAL_GetTick() - last_uart_time > 200)
    {
        float out_power = out_voltage * out_current;
        if (out_power < 0) out_power = 0; /* Prevent negative power display */

        char uart_buf[64];
        uint8_t nextion_end[3] = {0xFF, 0xFF, 0xFF};
        int len;

        /* t0: Current(A), t2: Voltage(V), t4: Power(W) */
        len = sprintf(uart_buf, "t0.txt=\"%.2f\"", out_current);
        HAL_UART_Transmit(&huart1, (uint8_t*)uart_buf, len, 50);
        HAL_UART_Transmit(&huart1, nextion_end, 3, 50);

        len = sprintf(uart_buf, "t2.txt=\"%.2f\"", out_voltage);
        HAL_UART_Transmit(&huart1, (uint8_t*)uart_buf, len, 50);
        HAL_UART_Transmit(&huart1, nextion_end, 3, 50);

        len = sprintf(uart_buf, "t4.txt=\"%.2f\"", out_power);
        HAL_UART_Transmit(&huart1, (uint8_t*)uart_buf, len, 50);
        HAL_UART_Transmit(&huart1, nextion_end, 3, 50);

        last_uart_time = HAL_GetTick();
    }
    /* USER CODE END WHILE */

    /* USER CODE BEGIN 3 */
  }
  /* USER CODE END 3 */
}

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
/* USER CODE BEGIN 4 */

/* UART RX Interrupt Callback */
void HAL_UART_RxCpltCallback(UART_HandleTypeDef *huart)
{
    if (huart->Instance == USART1)
    {
        if (rx_byte == '\n')
        {
            rx_line_buffer[rx_line_index] = '\0';
            strcpy(rx_line_copy, rx_line_buffer);
            rx_line_ready = 1;
            rx_line_index = 0;
        }
        else if (rx_byte != '\r' && rx_line_index < (sizeof(rx_line_buffer) - 1))
        {
            rx_line_buffer[rx_line_index++] = rx_byte;
        }
        HAL_UART_Receive_IT(&huart1, &rx_byte, 1);
    }
}

/* Nextion Data Parser */
void Process_Nextion_Command(char *line)
{
    char *colon_ptr = strchr(line, ':');
    if (colon_ptr != NULL)
    {
        float value = atof(colon_ptr + 1);

        /* System Commands */
        if (strncmp(line, "MODE", 4) == 0) System_Mode = (uint8_t)value;
        else if (strncmp(line, "RELAY", 5) == 0) Relay_State = (uint8_t)value;

        /* Voltage PI Commands */
        else if (strncmp(line, "SETV", 4) == 0) V_Ref = value;
        else if (strncmp(line, "KPV", 3) == 0) Kp_V = value;
        else if (strncmp(line, "KIV", 3) == 0) Ki_V = value;
        else if (strncmp(line, "OFFV", 4) == 0) V_Offset = value;
        else if (strncmp(line, "CALV", 4) == 0) V_Cal = value;

        /* Current PI Commands */
        else if (strncmp(line, "SETI", 4) == 0) I_Ref = value;
        else if (strncmp(line, "KPI", 3) == 0) Kp_I = value;
        else if (strncmp(line, "KII", 3) == 0) Ki_I = value;
        else if (strncmp(line, "OFFI", 4) == 0) I_Offset = value;
        else if (strncmp(line, "CALI", 4) == 0) I_Cal = value;

        /* Manual Commands */
        else if (strncmp(line, "DUTY", 4) == 0) Duty_Cycle = (int)value;
        else if (strncmp(line, "OFFM", 4) == 0) M_Offset = value;
    }
}
/* USER CODE END 4 */

void Error_Handler(void)
{
  __disable_irq();
  while (1)
  {
  }
}

#ifdef USE_FULL_ASSERT
void assert_failed(uint8_t *file, uint32_t line)
{
}
#endif /* USE_FULL_ASSERT */

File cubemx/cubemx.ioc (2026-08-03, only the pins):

Mcu.UserName=STM32F103C8Tx
PA11.Signal=USB_DM
PA12.Signal=USB_DP
PA13.Signal=SYS_JTMS-SWDIO
PA14.Signal=SYS_JTCK-SWCLK
PA15.Signal=SPI1_NSS
PA4.Signal=ADCx_IN4
PA5.Signal=ADCx_IN5
PA6.Signal=S_TIM3_CH1
PA7.Signal=GPIO_Output
PB10.Signal=I2C2_SCL
PB11.Signal=I2C2_SDA
PB3.Signal=SPI1_SCK
PB4.Signal=SPI1_MISO
PB5.Signal=SPI1_MOSI
PB6.Signal=USART1_TX
PB7.Signal=USART1_RX
PD0-OSC_IN.Signal=RCC_OSC_IN
PD1-OSC_OUT.Signal=RCC_OSC_OUT

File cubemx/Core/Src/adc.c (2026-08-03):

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
/* Includes ------------------------------------------------------------------*/
#include "adc.h"

ADC_HandleTypeDef hadc1;
DMA_HandleTypeDef hdma_adc1;

/* ADC1 init function */
void MX_ADC1_Init(void)
{

  ADC_ChannelConfTypeDef sConfig = {0};

  /** Common config
  */
  hadc1.Instance = ADC1;
  hadc1.Init.ScanConvMode = ADC_SCAN_ENABLE;
  hadc1.Init.ContinuousConvMode = ENABLE;
  hadc1.Init.DiscontinuousConvMode = DISABLE;
  hadc1.Init.ExternalTrigConv = ADC_SOFTWARE_START;
  hadc1.Init.DataAlign = ADC_DATAALIGN_RIGHT;
  hadc1.Init.NbrOfConversion = 2;
  if (HAL_ADC_Init(&hadc1) != HAL_OK)
  {
    Error_Handler();
  }

  /** Configure Regular Channel
  */
  sConfig.Channel = ADC_CHANNEL_4;
  sConfig.Rank = ADC_REGULAR_RANK_1;
  sConfig.SamplingTime = ADC_SAMPLETIME_1CYCLE_5;
  if (HAL_ADC_ConfigChannel(&hadc1, &sConfig) != HAL_OK)
  {
    Error_Handler();
  }

  /** Configure Regular Channel
  */
  sConfig.Channel = ADC_CHANNEL_5;
  sConfig.Rank = ADC_REGULAR_RANK_2;
  if (HAL_ADC_ConfigChannel(&hadc1, &sConfig) != HAL_OK)
  {
    Error_Handler();
  }
}

void HAL_ADC_MspInit(ADC_HandleTypeDef* adcHandle)
{

  GPIO_InitTypeDef GPIO_InitStruct = {0};
  if(adcHandle->Instance==ADC1)
  {
    /* ADC1 clock enable */
    __HAL_RCC_ADC1_CLK_ENABLE();

    __HAL_RCC_GPIOA_CLK_ENABLE();
    /**ADC1 GPIO Configuration
    PA4     ------> ADC1_IN4
    PA5     ------> ADC1_IN5
    */
    GPIO_InitStruct.Pin = GPIO_PIN_4|GPIO_PIN_5;
    GPIO_InitStruct.Mode = GPIO_MODE_ANALOG;
    HAL_GPIO_Init(GPIOA, &GPIO_InitStruct);

    /* ADC1 DMA Init */
    /* ADC1 Init */
    hdma_adc1.Instance = DMA1_Channel1;
    hdma_adc1.Init.Direction = DMA_PERIPH_TO_MEMORY;
    hdma_adc1.Init.PeriphInc = DMA_PINC_DISABLE;
    hdma_adc1.Init.MemInc = DMA_MINC_ENABLE;
    hdma_adc1.Init.PeriphDataAlignment = DMA_PDATAALIGN_HALFWORD;
    hdma_adc1.Init.MemDataAlignment = DMA_MDATAALIGN_HALFWORD;
    hdma_adc1.Init.Mode = DMA_CIRCULAR;
    hdma_adc1.Init.Priority = DMA_PRIORITY_LOW;
    if (HAL_DMA_Init(&hdma_adc1) != HAL_OK)
    {
      Error_Handler();
    }

    __HAL_LINKDMA(adcHandle,DMA_Handle,hdma_adc1);

  }
}

void HAL_ADC_MspDeInit(ADC_HandleTypeDef* adcHandle)
{

  if(adcHandle->Instance==ADC1)
  {
    /* Peripheral clock disable */
    __HAL_RCC_ADC1_CLK_DISABLE();

    /**ADC1 GPIO Configuration
    PA4     ------> ADC1_IN4
    PA5     ------> ADC1_IN5
    */
    HAL_GPIO_DeInit(GPIOA, GPIO_PIN_4|GPIO_PIN_5);

    /* ADC1 DMA DeInit */
    HAL_DMA_DeInit(adcHandle->DMA_Handle);
  }
}



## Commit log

2026-08-03 add Schematic and PCB files
    [buck converter V6.kicad_pcb, buck converter V6.kicad_sch]
2026-08-03 add STEP file
    [.step]
2026-08-03 Create schematic-pcb-3d-pdfs
2026-08-03 Create Gerber File
2026-08-03 add Gerber Files
    [buck converter V6-B_Cu.gbl, buck converter V6-B_Fab.gbr, buck converter V6-B_Mask.gbs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]
2026-08-03 Create BOM list
2026-08-03 add BOM Lists
    [buck converter V6.xls]
2026-08-17 Minor Update
    [.step, buck converter V6.xls]

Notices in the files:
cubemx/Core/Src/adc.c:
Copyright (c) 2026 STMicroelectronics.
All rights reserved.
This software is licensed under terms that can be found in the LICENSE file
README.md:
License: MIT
